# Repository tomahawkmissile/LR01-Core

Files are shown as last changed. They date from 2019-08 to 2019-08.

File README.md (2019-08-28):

# LR01-Core
Core controller of the LR-01 hybrid drone. Controls rotors, critical cooling, battery charge/discharge controllers and realtime sensors.

Aircraft specifications will be posted in another repository.
***Note: these files are about 95% complete.***

Features:
- TI AM3354 Arm Cortex-A8
- 512MB DDR3 (800MHz)
- HDMI out
- 1 Gigabit ethernet
- 2 USB 2.0
- 2 16GB eMCC flash
- 1 Application connector
- 12 layer PCB

***Note: this board may or may not function.***

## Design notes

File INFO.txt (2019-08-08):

**This file contains information about the design files contained here.**

***Further modification needed***

**All units are metric.**

> Board materials + specifications
---> Laminate				FR4
---> Layer count			10
---> Total thickness			1.9mm (Can be rounded to 2.0mm if needed. See note in layer stack section.)
---> Length				97.79mm
---> Width				82.55mm
---> Finish type			HASL
---> Copper weight			35 micrometers for all layers
---> Soldermask color			Matte black
---> Silkscreen location		Both sides (top and bottom)
---> Silkscreen color			White
---> Silkscreen type			LPI
---> Impedance matching			10% tolerance
---> Stacked microvias			No
---> Blind vias				No
---> Buried vias			No
---> Minimum drill diameter		0.15mm
---> Minimum annular ring thickness	0.1mm (adding 0.2mm to the vias diameter)
---> Smallest trace width		0.1016mm
---> Smallest spacing			0.0762mm
---> Via in pad				Yes
---> Via plug				None
---> Stencil				Top and bottom (separate)

> Specific layer stack
---> Copper layer 1			0.035mm
---> Prepreg 1				0.1mm
---> Copper layer 2			0.035mm
---> Core 1				0.22mm
---> Copper layer 3			0.035mm
---> Prepreg 2				0.25mm
---> Copper layer 4			0.035mm
---> Core 2				0.15mm
---> Copper layer 5			0.035mm
---> Prepreg 3				0.2mm
---> Copper layer 6			0.035mm
---> Core 3				0.15mm
---> Copper layer 7			0.035mm
---> Prepreg 4				0.25mm
---> Copper layer 8			0.035mm
---> Core 4				0.22mm
---> Copper layer 9			0.035mm
---> Prepreg 5				0.1mm
---> Copper layer 10			0.035mm

---> Total				1.9mm

>Impedance control stack
---> 50 Ohms between copper layer 1-2, 2-3, 7-8, and 8-9.

***If rounding to 2.0mm is needed, round the Prepreg 3 layer to 0.3mm.***

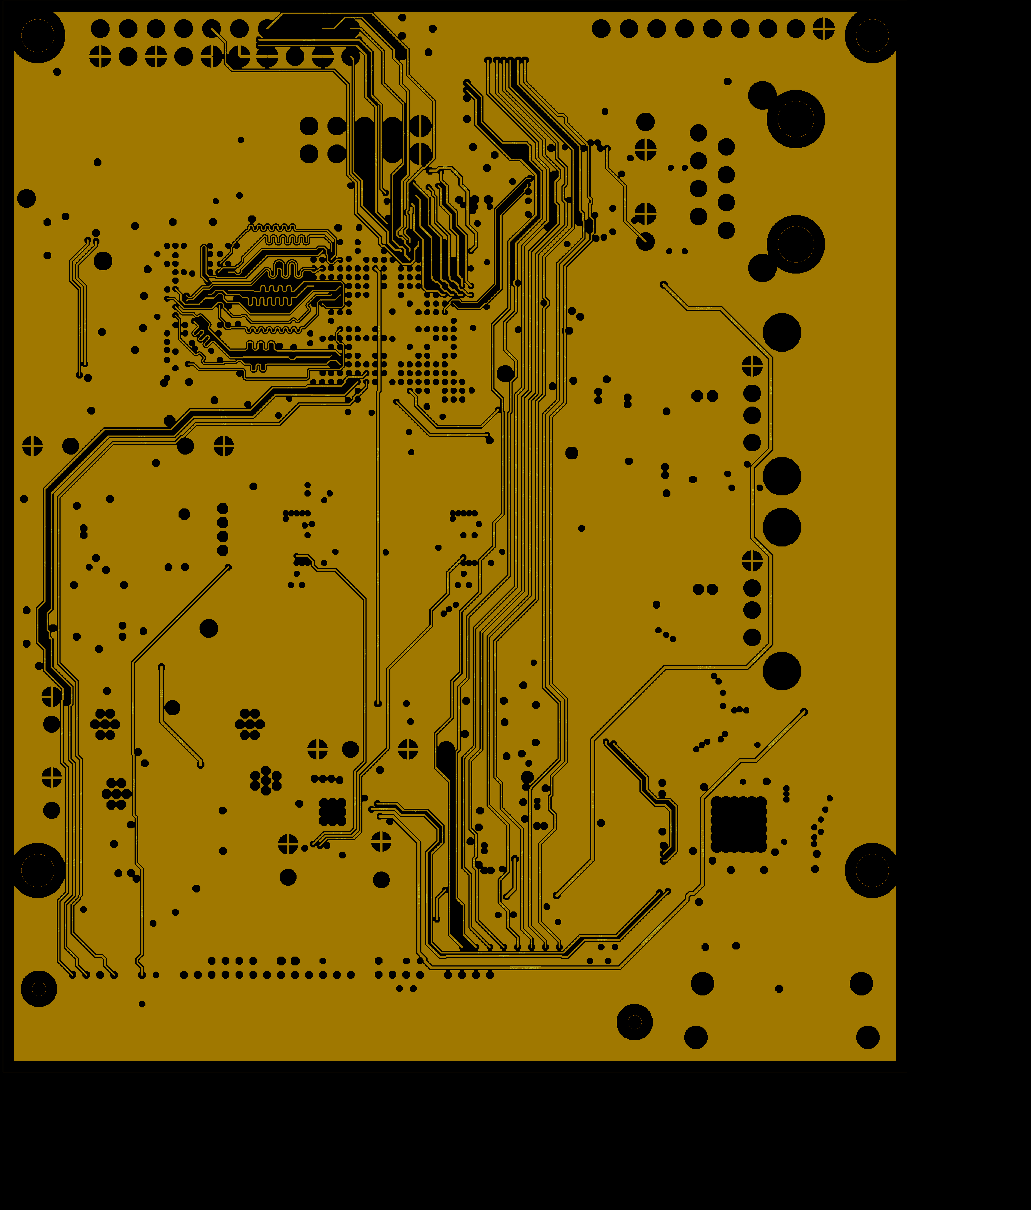
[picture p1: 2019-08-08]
l3.png

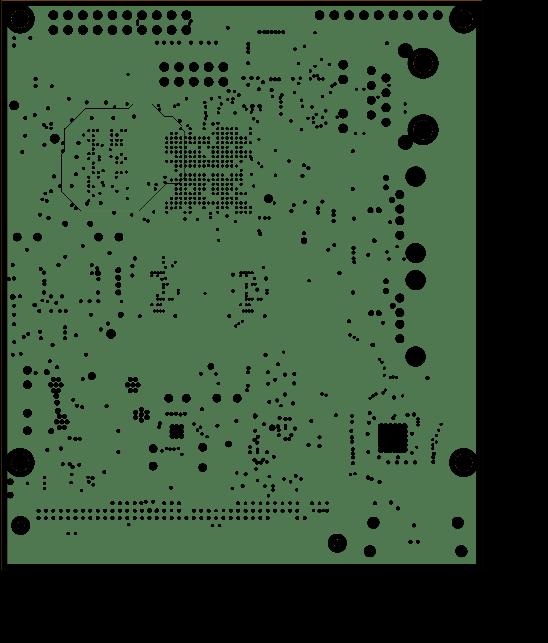
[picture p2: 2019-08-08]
l12.png

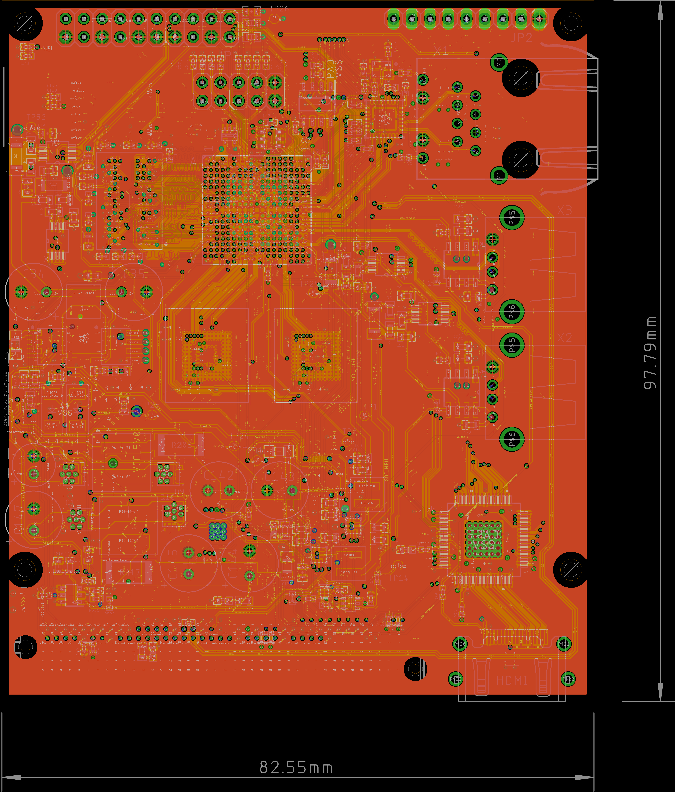
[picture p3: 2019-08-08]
whole-6-22-19.png

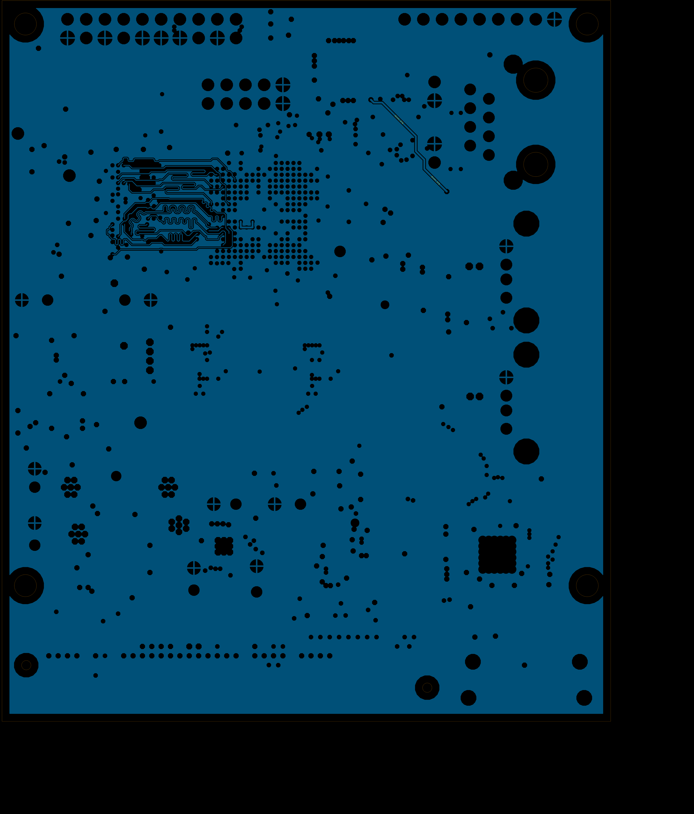
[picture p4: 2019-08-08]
l15.png

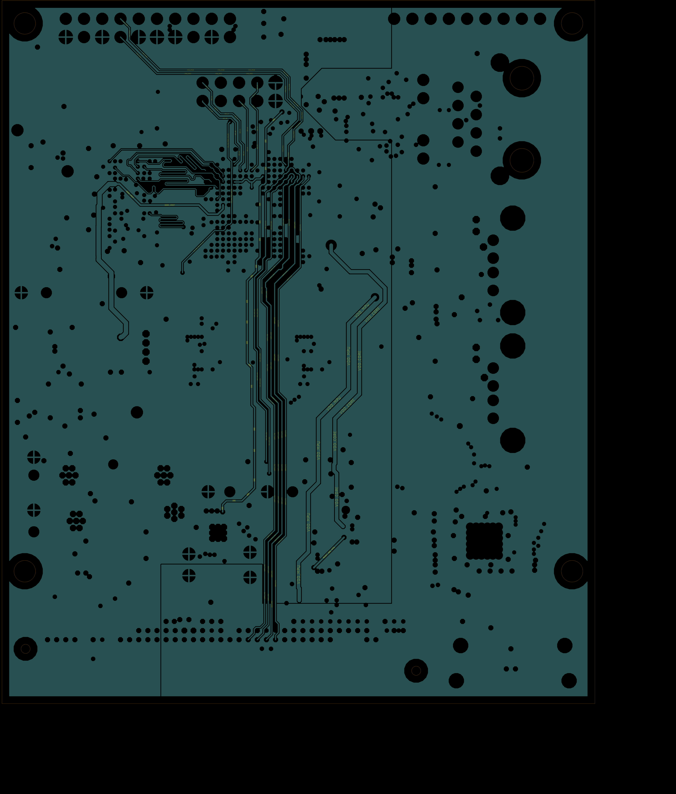
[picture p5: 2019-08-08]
l13.png

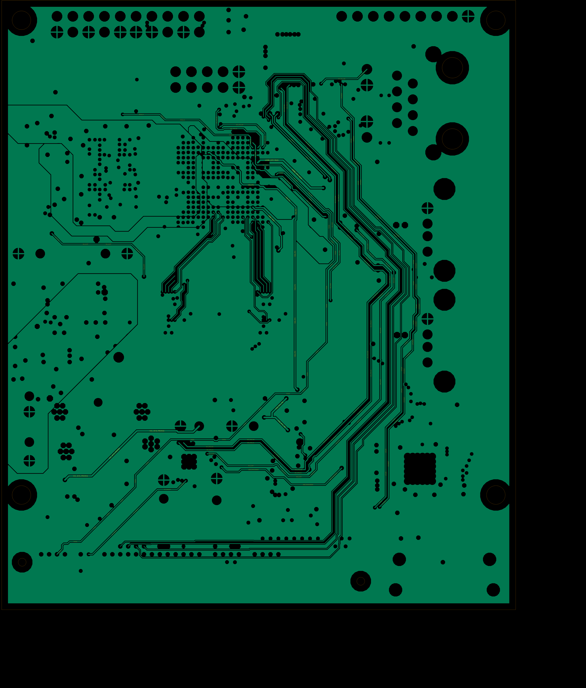
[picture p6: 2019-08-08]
l14.png

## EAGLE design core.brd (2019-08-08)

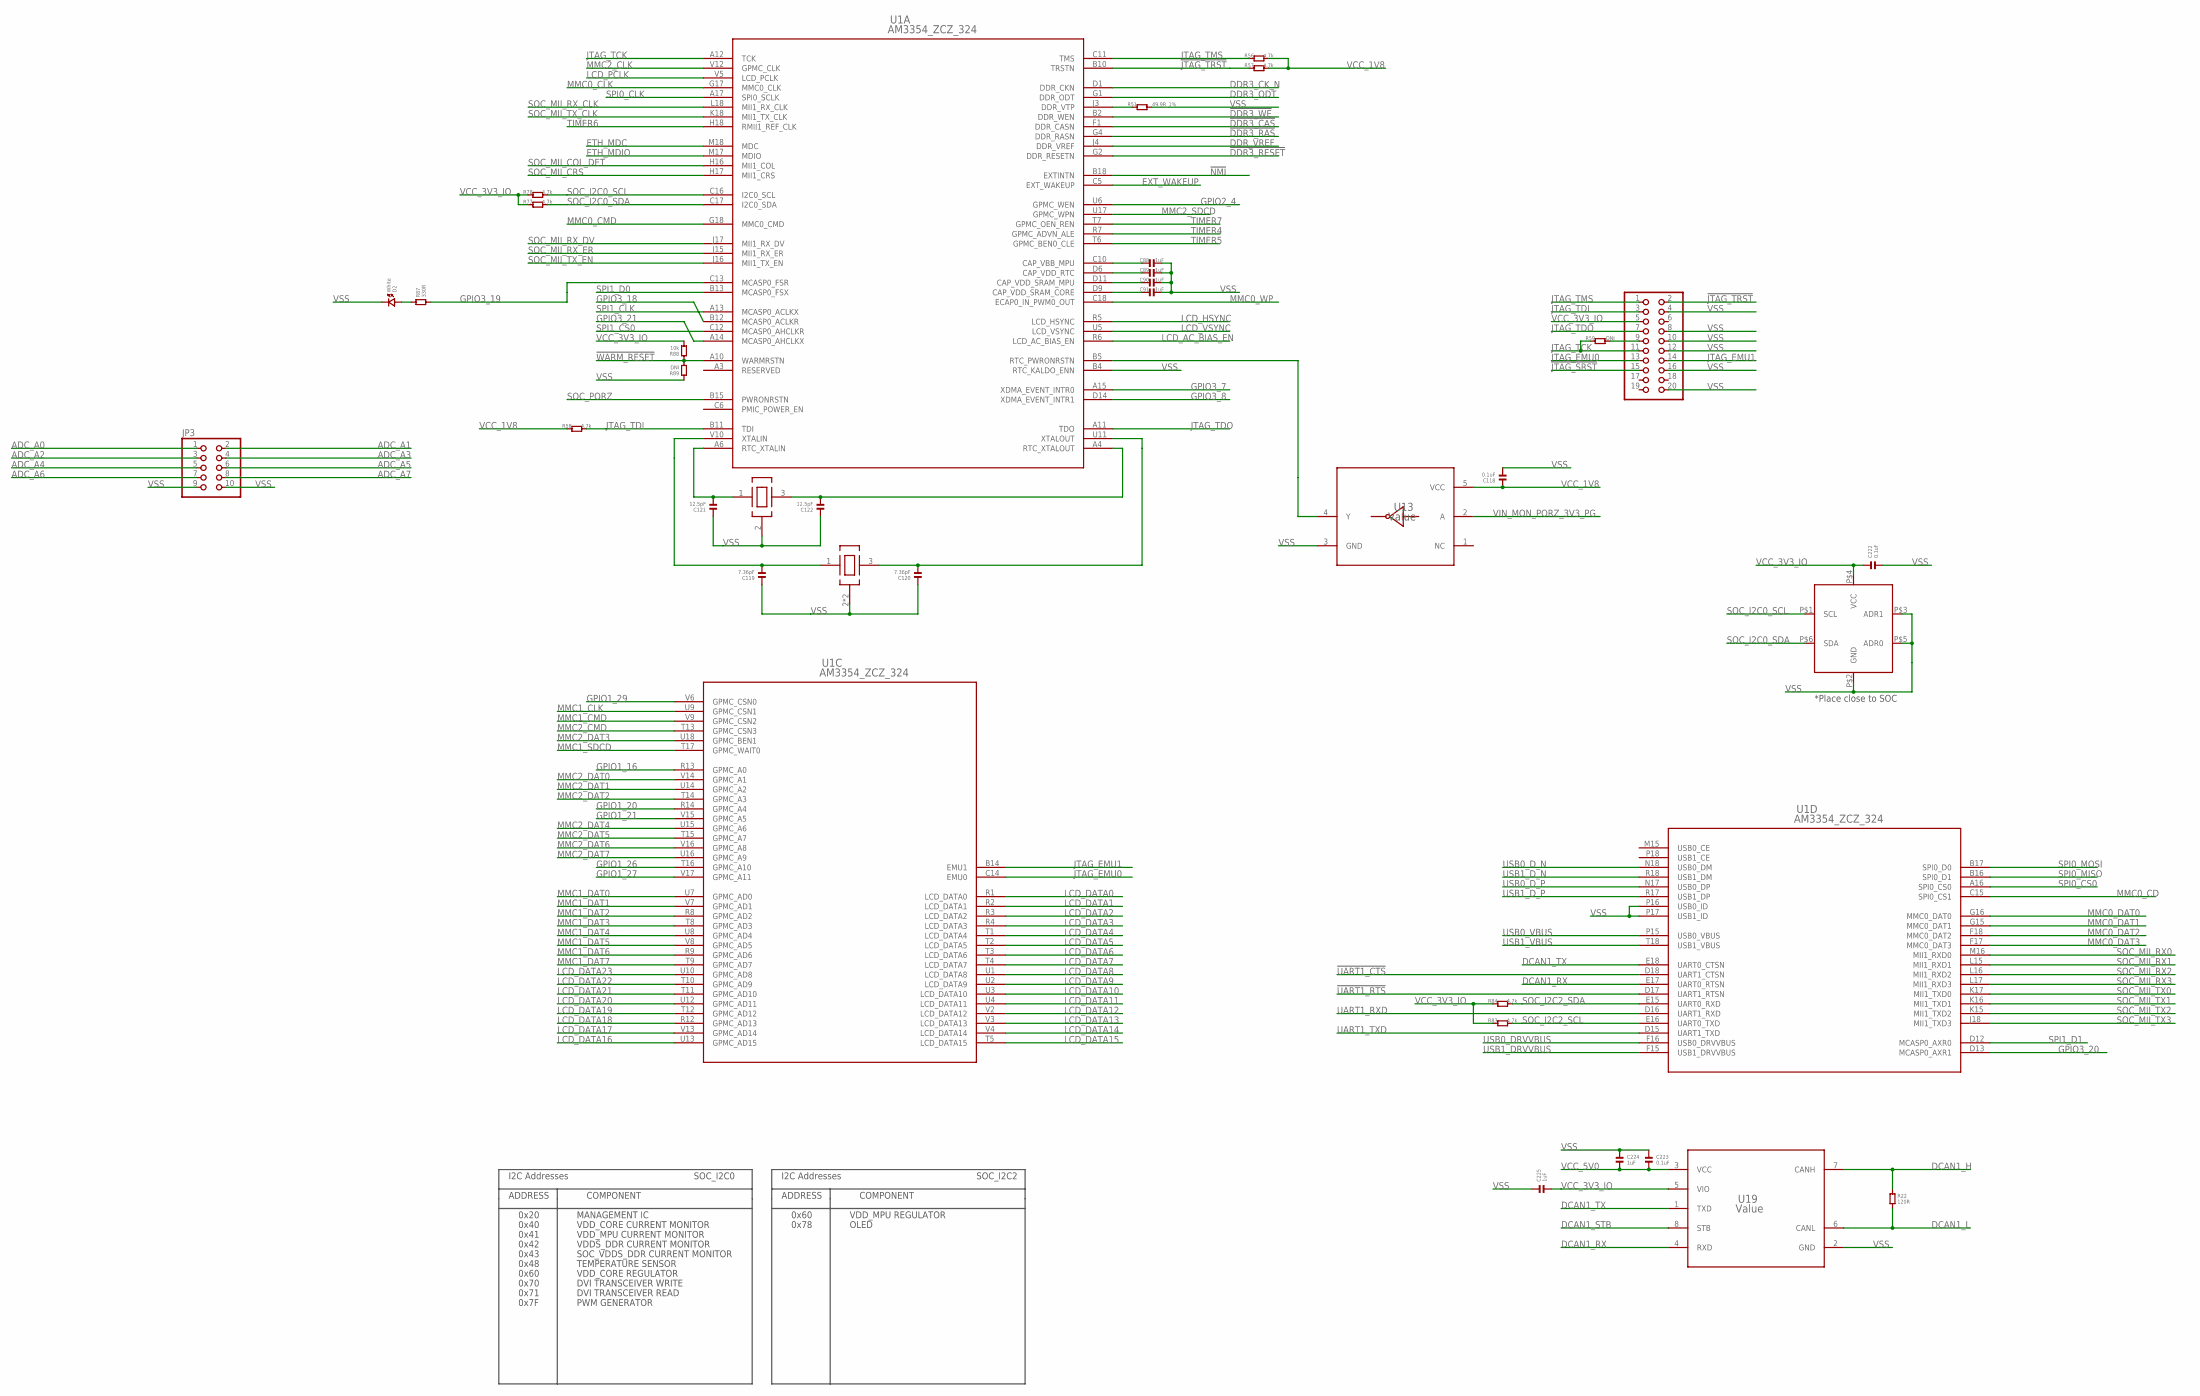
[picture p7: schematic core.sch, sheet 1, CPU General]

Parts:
C88, C89, C90, C91: 1uF; 0201
C118, C222, C223: 0.1uF; 0402
C119, C120: 7.36pF; 0402
C121, C122: 12.5pF; 0402
C224, C225: 1uF; 0402
D2: White; 0603.LED
JP1: PINHD-2X10; 2X10
JP3: PINHD-2X5; 2X05
R22: 120R; 0402
R51: 49.9R_1%; 0201
R56, R57, R58: 4.7k; 0603
R59, R89: DNI; 0402
R77, R78, R83, R84: 4.7k; 0402
R87: 330R; 0603
R88: 10k; 0402
U1: AM3354_ZCZ_324; ZCZ324
U13: Value; DCK0005A_N
U19: Value; D0008A_N
U$5: ECS-.327-12.5-1210B-N-TR; OSCCC120X100X35
U$6: NX3225SA-26.000000MHZ-G3; OSCCC320X250X70
U$9: TMP100; SOT23-6

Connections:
!DDR3_CAS: U1.F1 (DDR_CASN); also elsewhere on the board
!DDR3_RAS: U1.G4 (DDR_RASN); also elsewhere on the board
!DDR3_RESET: U1.G2 (DDR_RESETN); also elsewhere on the board
!DDR3_WE: U1.B2 (DDR_WEN); also elsewhere on the board
!JTAG_SRST: JP1.15
!JTAG_TRST: JP1.2, R57.1, U1.B10 (TRSTN); also elsewhere on the board
!NMI: U1.B18 (EXTINTN); also elsewhere on the board
!UART1_CTS: U1.D18 (UART1_CTSN); also elsewhere on the board
!UART1_RTS: U1.D17 (UART1_RTSN); also elsewhere on the board
!WARM_RESET: R88.1, R89.2, U1.A10 (WARMRSTN); also elsewhere on the board
ADC_A0: JP3.1; also elsewhere on the board
ADC_A1: JP3.2; also elsewhere on the board
ADC_A2: JP3.3; also elsewhere on the board
ADC_A3: JP3.4; also elsewhere on the board
ADC_A4: JP3.5; also elsewhere on the board
ADC_A5: JP3.6; also elsewhere on the board
ADC_A6: JP3.7; also elsewhere on the board
ADC_A7: JP3.8; also elsewhere on the board
DCAN1_H: R22.1, U19.7 (CANH); also elsewhere on the board
DCAN1_L: R22.2, U19.6 (CANL); also elsewhere on the board
DCAN1_RX: U1.E17 (UART0_RTSN), U19.4 (RXD)
DCAN1_STB: U19.8 (STB); also elsewhere on the board
DCAN1_TX: U1.E18 (UART0_CTSN), U19.1 (TXD)
DDR3_CK_N: U1.D1 (DDR_CKN); also elsewhere on the board
DDR3_ODT: U1.G1 (DDR_ODT); also elsewhere on the board
DDR_VREF: U1.J4 (DDR_VREF); also elsewhere on the board
ETH_MDC: U1.M18 (MDC); also elsewhere on the board
ETH_MDIO: U1.M17 (MDIO); also elsewhere on the board
EXT_WAKEUP: U1.C5 (EXT_WAKEUP); also elsewhere on the board
GPIO1_16: U1.R13 (GPMC_A0); also elsewhere on the board
GPIO1_20: U1.R14 (GPMC_A4); also elsewhere on the board
GPIO1_21: U1.V15 (GPMC_A5); also elsewhere on the board
GPIO1_26: U1.T16 (GPMC_A10); also elsewhere on the board
GPIO1_27: U1.V17 (GPMC_A11); also elsewhere on the board
GPIO1_29: U1.V6 (GPMC_CSN0); also elsewhere on the board
GPIO2_4: U1.U6 (GPMC_WEN); also elsewhere on the board
GPIO3_7: U1.A15 (XDMA_EVENT_INTR0); also elsewhere on the board
GPIO3_8: U1.D14 (XDMA_EVENT_INTR1); also elsewhere on the board
GPIO3_18: U1.B12 (MCASP0_ACLKR); also elsewhere on the board
GPIO3_19: R87.2, U1.C13 (MCASP0_FSR); also elsewhere on the board
GPIO3_20: U1.D13 (MCASP0_AXR1); also elsewhere on the board
GPIO3_21: U1.A14 (MCASP0_AHCLKX); also elsewhere on the board
JTAG_EMU0: JP1.13, U1.C14 (EMU0)
JTAG_EMU1: JP1.14, U1.B14 (EMU1)
JTAG_TCK: JP1.11, R59.1, U1.A12 (TCK)
JTAG_TDI: JP1.3, R58.2, U1.B11 (TDI)
JTAG_TDO: JP1.7, U1.A11 (TDO)
JTAG_TMS: JP1.1, R56.1, U1.C11 (TMS)
LCD_AC_BIAS_EN: U1.R6 (LCD_AC_BIAS_EN); also elsewhere on the board
LCD_DATA0: U1.R1 (LCD_DATA0); also elsewhere on the board
LCD_DATA1: U1.R2 (LCD_DATA1); also elsewhere on the board
LCD_DATA2: U1.R3 (LCD_DATA2); also elsewhere on the board
LCD_DATA3: U1.R4 (LCD_DATA3); also elsewhere on the board
LCD_DATA4: U1.T1 (LCD_DATA4); also elsewhere on the board
LCD_DATA5: U1.T2 (LCD_DATA5); also elsewhere on the board
LCD_DATA6: U1.T3 (LCD_DATA6); also elsewhere on the board
LCD_DATA7: U1.T4 (LCD_DATA7); also elsewhere on the board
LCD_DATA8: U1.U1 (LCD_DATA8); also elsewhere on the board
LCD_DATA9: U1.U2 (LCD_DATA9); also elsewhere on the board
LCD_DATA10: U1.U3 (LCD_DATA10); also elsewhere on the board
LCD_DATA11: U1.U4 (LCD_DATA11); also elsewhere on the board
LCD_DATA12: U1.V2 (LCD_DATA12); also elsewhere on the board
LCD_DATA13: U1.V3 (LCD_DATA13); also elsewhere on the board
LCD_DATA14: U1.V4 (LCD_DATA14); also elsewhere on the board
LCD_DATA15: U1.T5 (LCD_DATA15); also elsewhere on the board
LCD_DATA16: U1.U13 (GPMC_AD15); also elsewhere on the board
LCD_DATA17: U1.V13 (GPMC_AD14); also elsewhere on the board
LCD_DATA18: U1.R12 (GPMC_AD13); also elsewhere on the board
LCD_DATA19: U1.T12 (GPMC_AD12); also elsewhere on the board
LCD_DATA20: U1.U12 (GPMC_AD11); also elsewhere on the board
LCD_DATA21: U1.T11 (GPMC_AD10); also elsewhere on the board
LCD_DATA22: U1.T10 (GPMC_AD9); also elsewhere on the board
LCD_DATA23: U1.U10 (GPMC_AD8); also elsewhere on the board
LCD_HSYNC: U1.R5 (LCD_HSYNC); also elsewhere on the board
LCD_PCLK: U1.V5 (LCD_PCLK); also elsewhere on the board
LCD_VSYNC: U1.U5 (LCD_VSYNC); also elsewhere on the board
MMC0_CD: U1.C15 (SPI0_CS1); also elsewhere on the board
MMC0_CLK: U1.G17 (MMC0_CLK); also elsewhere on the board
MMC0_CMD: U1.G18 (MMC0_CMD); also elsewhere on the board
MMC0_DAT0: U1.G16 (MMC0_DAT0); also elsewhere on the board
MMC0_DAT1: U1.G15 (MMC0_DAT1); also elsewhere on the board
MMC0_DAT2: U1.F18 (MMC0_DAT2); also elsewhere on the board
MMC0_DAT3: U1.F17 (MMC0_DAT3); also elsewhere on the board
MMC0_WP: U1.C18 (ECAP0_IN_PWM0_OUT); also elsewhere on the board
MMC1_CLK: U1.U9 (GPMC_CSN1); also elsewhere on the board
MMC1_CMD: U1.V9 (GPMC_CSN2); also elsewhere on the board
MMC1_DAT0: U1.U7 (GPMC_AD0); also elsewhere on the board
MMC1_DAT1: U1.V7 (GPMC_AD1); also elsewhere on the board
MMC1_DAT2: U1.R8 (GPMC_AD2); also elsewhere on the board
MMC1_DAT3: U1.T8 (GPMC_AD3); also elsewhere on the board
MMC1_DAT4: U1.U8 (GPMC_AD4); also elsewhere on the board
MMC1_DAT5: U1.V8 (GPMC_AD5); also elsewhere on the board
MMC1_DAT6: U1.R9 (GPMC_AD6); also elsewhere on the board
MMC1_DAT7: U1.T9 (GPMC_AD7); also elsewhere on the board
MMC1_SDCD: U1.T17 (GPMC_WAIT0)
MMC2_CLK: U1.V12 (GPMC_CLK); also elsewhere on the board
MMC2_CMD: U1.T13 (GPMC_CSN3); also elsewhere on the board
MMC2_DAT0: U1.V14 (GPMC_A1); also elsewhere on the board
MMC2_DAT1: U1.U14 (GPMC_A2); also elsewhere on the board
MMC2_DAT2: U1.T14 (GPMC_A3); also elsewhere on the board
MMC2_DAT3: U1.U18 (GPMC_BEN1); also elsewhere on the board
MMC2_DAT4: U1.U15 (GPMC_A6); also elsewhere on the board
MMC2_DAT5: U1.T15 (GPMC_A7); also elsewhere on the board
MMC2_DAT6: U1.V16 (GPMC_A8); also elsewhere on the board
MMC2_DAT7: U1.U16 (GPMC_A9); also elsewhere on the board
MMC2_SDCD: U1.U17 (GPMC_WPN)
unnamed: JP1.9, R59.2
unnamed: C88.1, U1.C10 (CAP_VBB_MPU)
unnamed: C91.1, U1.D9 (CAP_VDD_SRAM_CORE)
unnamed: C90.1, U1.D11 (CAP_VDD_SRAM_MPU)
unnamed: U1.B5 (RTC_PWRONRSTN), U13.4 (Y)
unnamed: C121.2, U1.A6 (RTC_XTALIN), U$5.1 (XI)
unnamed: C122.2, U1.A4 (RTC_XTALOUT), U$5.3 (XO)
unnamed: C119.2, U1.V10 (XTALIN), U$6.1 (XI)
unnamed: C120.2, U1.U11 (XTALOUT), U$6.3 (XO)
unnamed: R51.1, U1.J3 (DDR_VTP)
unnamed: C89.1, U1.D6 (CAP_VDD_RTC)
unnamed: D2.P$1 (1), R87.1
SOC_I2C0_SCL: R78.2, U1.C16 (I2C0_SCL), U$9.P$1 (SCL); also elsewhere on the board
SOC_I2C0_SDA: R77.2, U1.C17 (I2C0_SDA), U$9.P$6 (SDA); also elsewhere on the board
SOC_I2C2_SCL: R83.2, U1.E16 (UART0_TXD); also elsewhere on the board
SOC_I2C2_SDA: R84.2, U1.E15 (UART0_RXD); also elsewhere on the board
SOC_MII_COL_DET: U1.H16 (MII1_COL); also elsewhere on the board
SOC_MII_CRS: U1.H17 (MII1_CRS); also elsewhere on the board
SOC_MII_RX0: U1.M16 (MII1_RXD0); also elsewhere on the board
SOC_MII_RX1: U1.L15 (MII1_RXD1); also elsewhere on the board
SOC_MII_RX2: U1.L16 (MII1_RXD2); also elsewhere on the board
SOC_MII_RX3: U1.L17 (MII1_RXD3); also elsewhere on the board
SOC_MII_RX_CLK: U1.L18 (MII1_RX_CLK); also elsewhere on the board
SOC_MII_RX_DV: U1.J17 (MII1_RX_DV); also elsewhere on the board
SOC_MII_RX_ER: U1.J15 (MII1_RX_ER); also elsewhere on the board
SOC_MII_TX0: U1.K17 (MII1_TXD0); also elsewhere on the board
SOC_MII_TX1: U1.K16 (MII1_TXD1); also elsewhere on the board
SOC_MII_TX2: U1.K15 (MII1_TXD2); also elsewhere on the board
SOC_MII_TX3: U1.J18 (MII1_TXD3); also elsewhere on the board
SOC_MII_TX_CLK: U1.K18 (MII1_TX_CLK); also elsewhere on the board
SOC_MII_TX_EN: U1.J16 (MII1_TX_EN); also elsewhere on the board
SOC_PORZ: U1.B15 (PWRONRSTN); also elsewhere on the board
SPI0_CLK: U1.A17 (SPI0_SCLK); also elsewhere on the board
SPI0_CS0: U1.A16 (SPI0_CS0); also elsewhere on the board
SPI0_MISO: U1.B16 (SPI0_D1); also elsewhere on the board
SPI0_MOSI: U1.B17 (SPI0_D0); also elsewhere on the board
SPI1_CLK: U1.A13 (MCASP0_ACLKX); also elsewhere on the board
SPI1_CS0: U1.C12 (MCASP0_AHCLKR); also elsewhere on the board
SPI1_D0: U1.B13 (MCASP0_FSX); also elsewhere on the board
SPI1_D1: U1.D12 (MCASP0_AXR0); also elsewhere on the board
TIMER4: U1.R7 (GPMC_ADVN_ALE); also elsewhere on the board
TIMER5: U1.T6 (GPMC_BEN0_CLE); also elsewhere on the board
TIMER6: U1.H18 (RMII1_REF_CLK); also elsewhere on the board
TIMER7: U1.T7 (GPMC_OEN_REN); also elsewhere on the board
UART1_RXD: U1.D16 (UART1_RXD); also elsewhere on the board
UART1_TXD: U1.D15 (UART1_TXD); also elsewhere on the board
USB0_DRVVBUS: U1.F16 (USB0_DRVVBUS); also elsewhere on the board
USB0_D_N: U1.N18 (USB0_DM); also elsewhere on the board
USB0_D_P: U1.N17 (USB0_DP); also elsewhere on the board
USB0_VBUS: U1.P15 (USB0_VBUS); also elsewhere on the board
USB1_DRVVBUS: U1.F15 (USB1_DRVVBUS); also elsewhere on the board
USB1_D_N: U1.R18 (USB1_DM); also elsewhere on the board
USB1_D_P: U1.R17 (USB1_DP); also elsewhere on the board
USB1_VBUS: U1.T18 (USB1_VBUS); also elsewhere on the board
VCC_1V8: C118.1, R56.2, R57.2, R58.1, U13.5 (VCC); also elsewhere on the board
VCC_3V3_IO: C222.1, C225.2, JP1.5, R77.1, R78.1, R83.1, R84.1, R88.2, U19.5 (VIO), U$9.P$4 (VCC); also elsewhere on the board
VCC_5V0: C223.2, C224.2, U19.3 (VCC); also elsewhere on the board
VIN_MON_PORZ_3V3_PG: U13.2 (A); also elsewhere on the board
VPP: U1.M5 (VPP)
VSS: C88.2, C89.2, C90.2, C91.2, C118.2, C119.1, C120.1, C121.1, C122.1, C222.2, C223.1, C224.1, C225.1, D2.P$2 (2), JP1.4, JP1.8, JP1.10, JP1.12, JP1.16, JP1.20, JP3.9, JP3.10, R51.2, R89.1, U1.B4 (RTC_KALDO_ENN), U1.P16 (USB0_ID), U1.P17 (USB1_ID), U13.3 (GND), U19.2 (GND), U$5.2 (VSS), U$6.2 (VSS), U$6.4 (VSS), U$9.P$2 (GND), U$9.P$3 (ADR1), U$9.P$5 (ADR0); also elsewhere on the board

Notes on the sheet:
I2C Addresses
0x20
MANAGEMENT IC
ADDRESS
COMPONENT
0x40
0x41
0x42
0x43
VDD_CORE CURRENT MONITOR
VDD_MPU CURRENT MONITOR
VDDS_DDR CURRENT MONITOR
SOC_VDDS_DDR CURRENT MONITOR
0x60
VDD_CORE REGULATOR
SOC_I2C0
VDD_MPU REGULATOR
SOC_I2C2
0x70
0x71
DVI TRANSCEIVER WRITE
DVI TRANSCEIVER READ
0x78
OLED
0x48
TEMPERATURE SENSOR
*Place close to SOC
0x7F
PWM GENERATOR

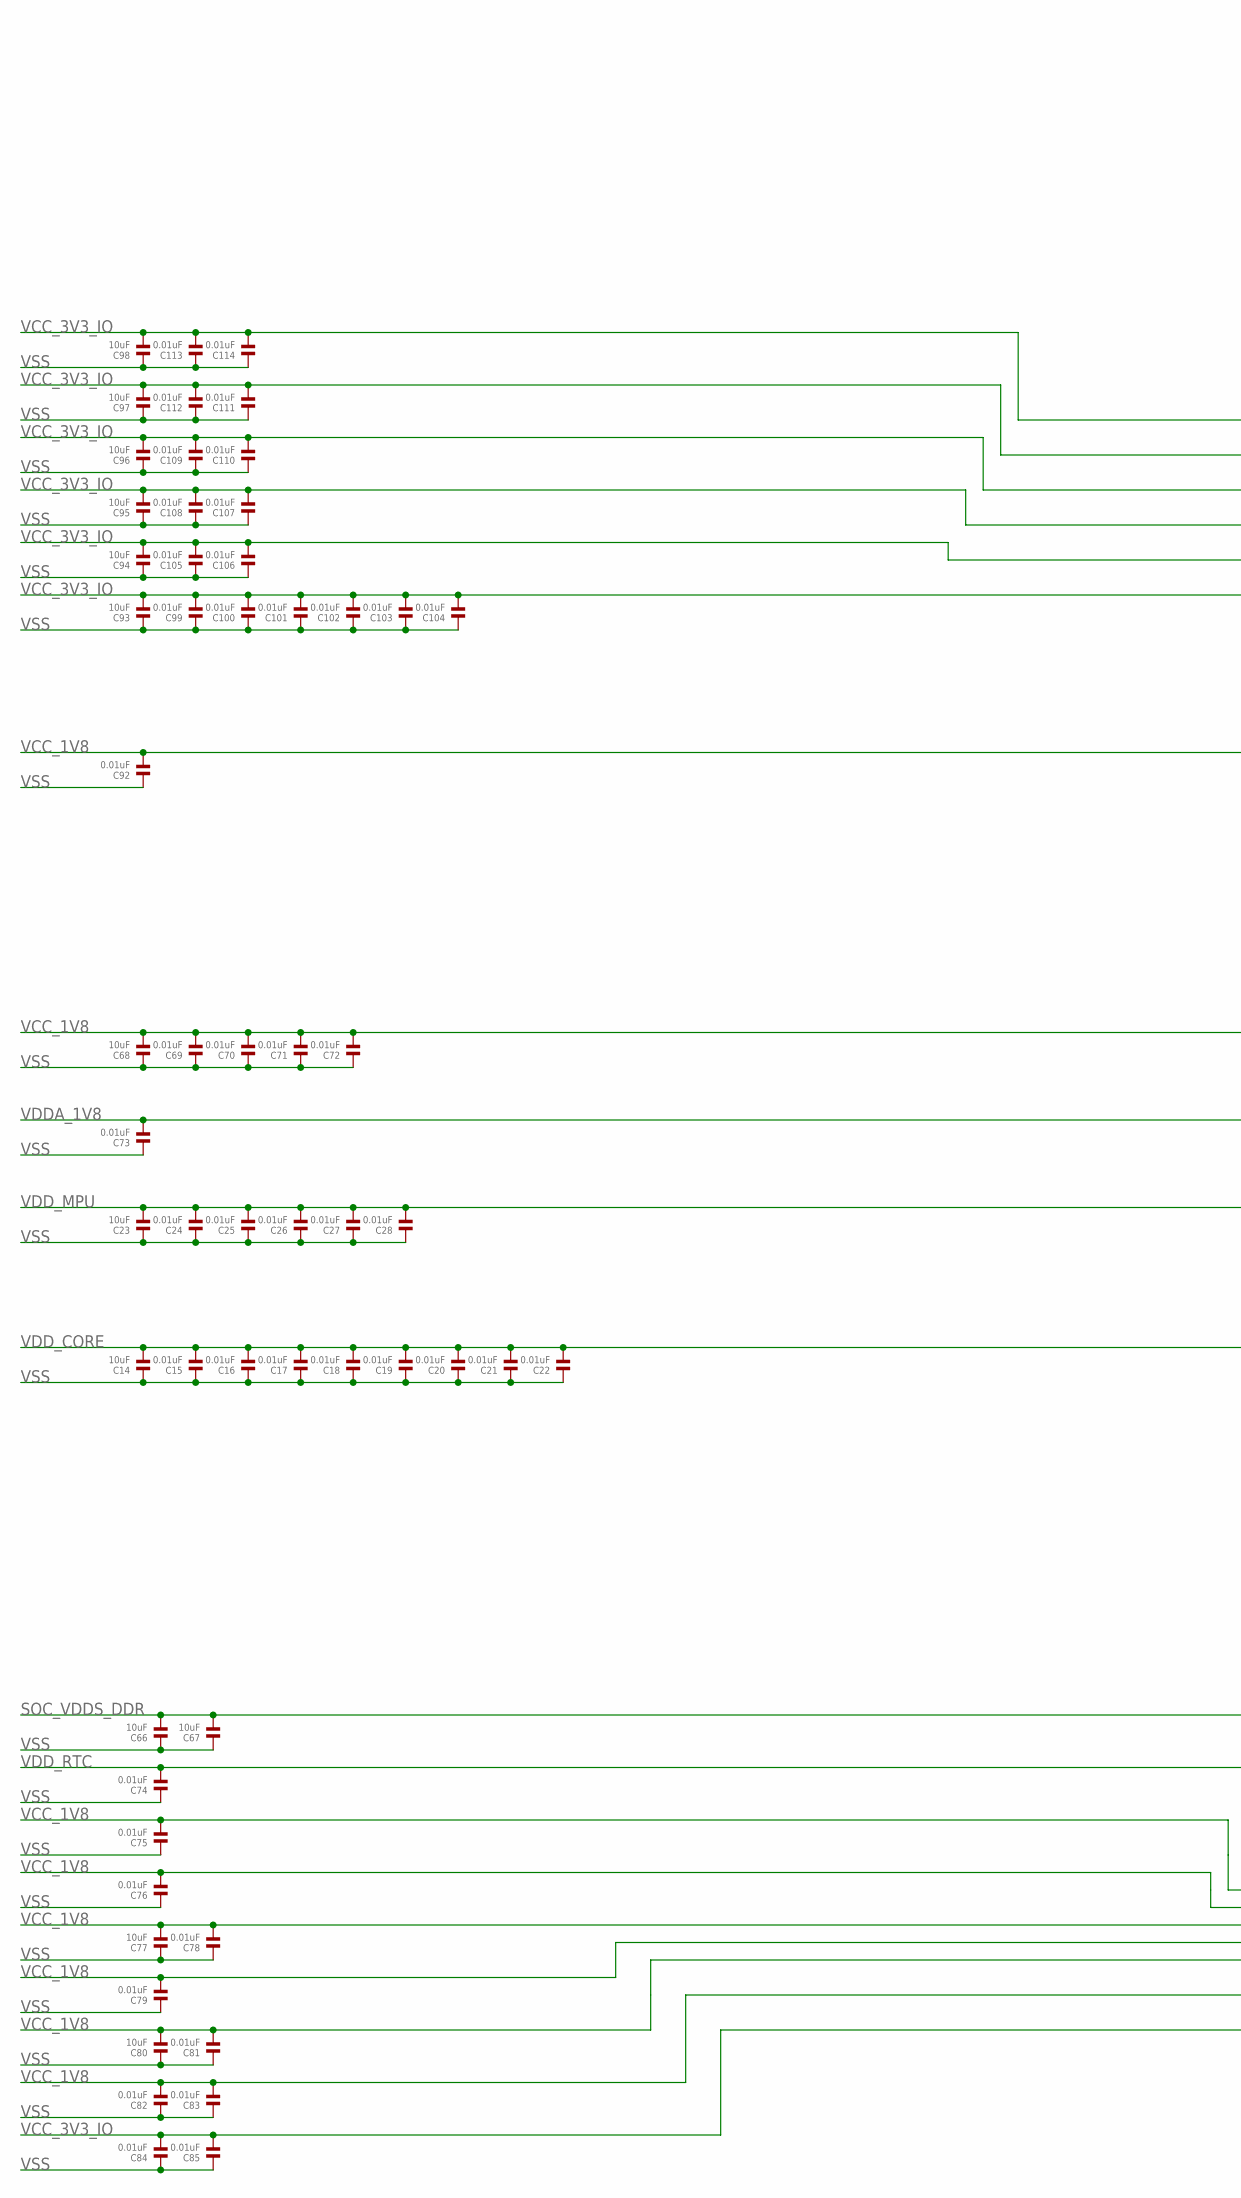
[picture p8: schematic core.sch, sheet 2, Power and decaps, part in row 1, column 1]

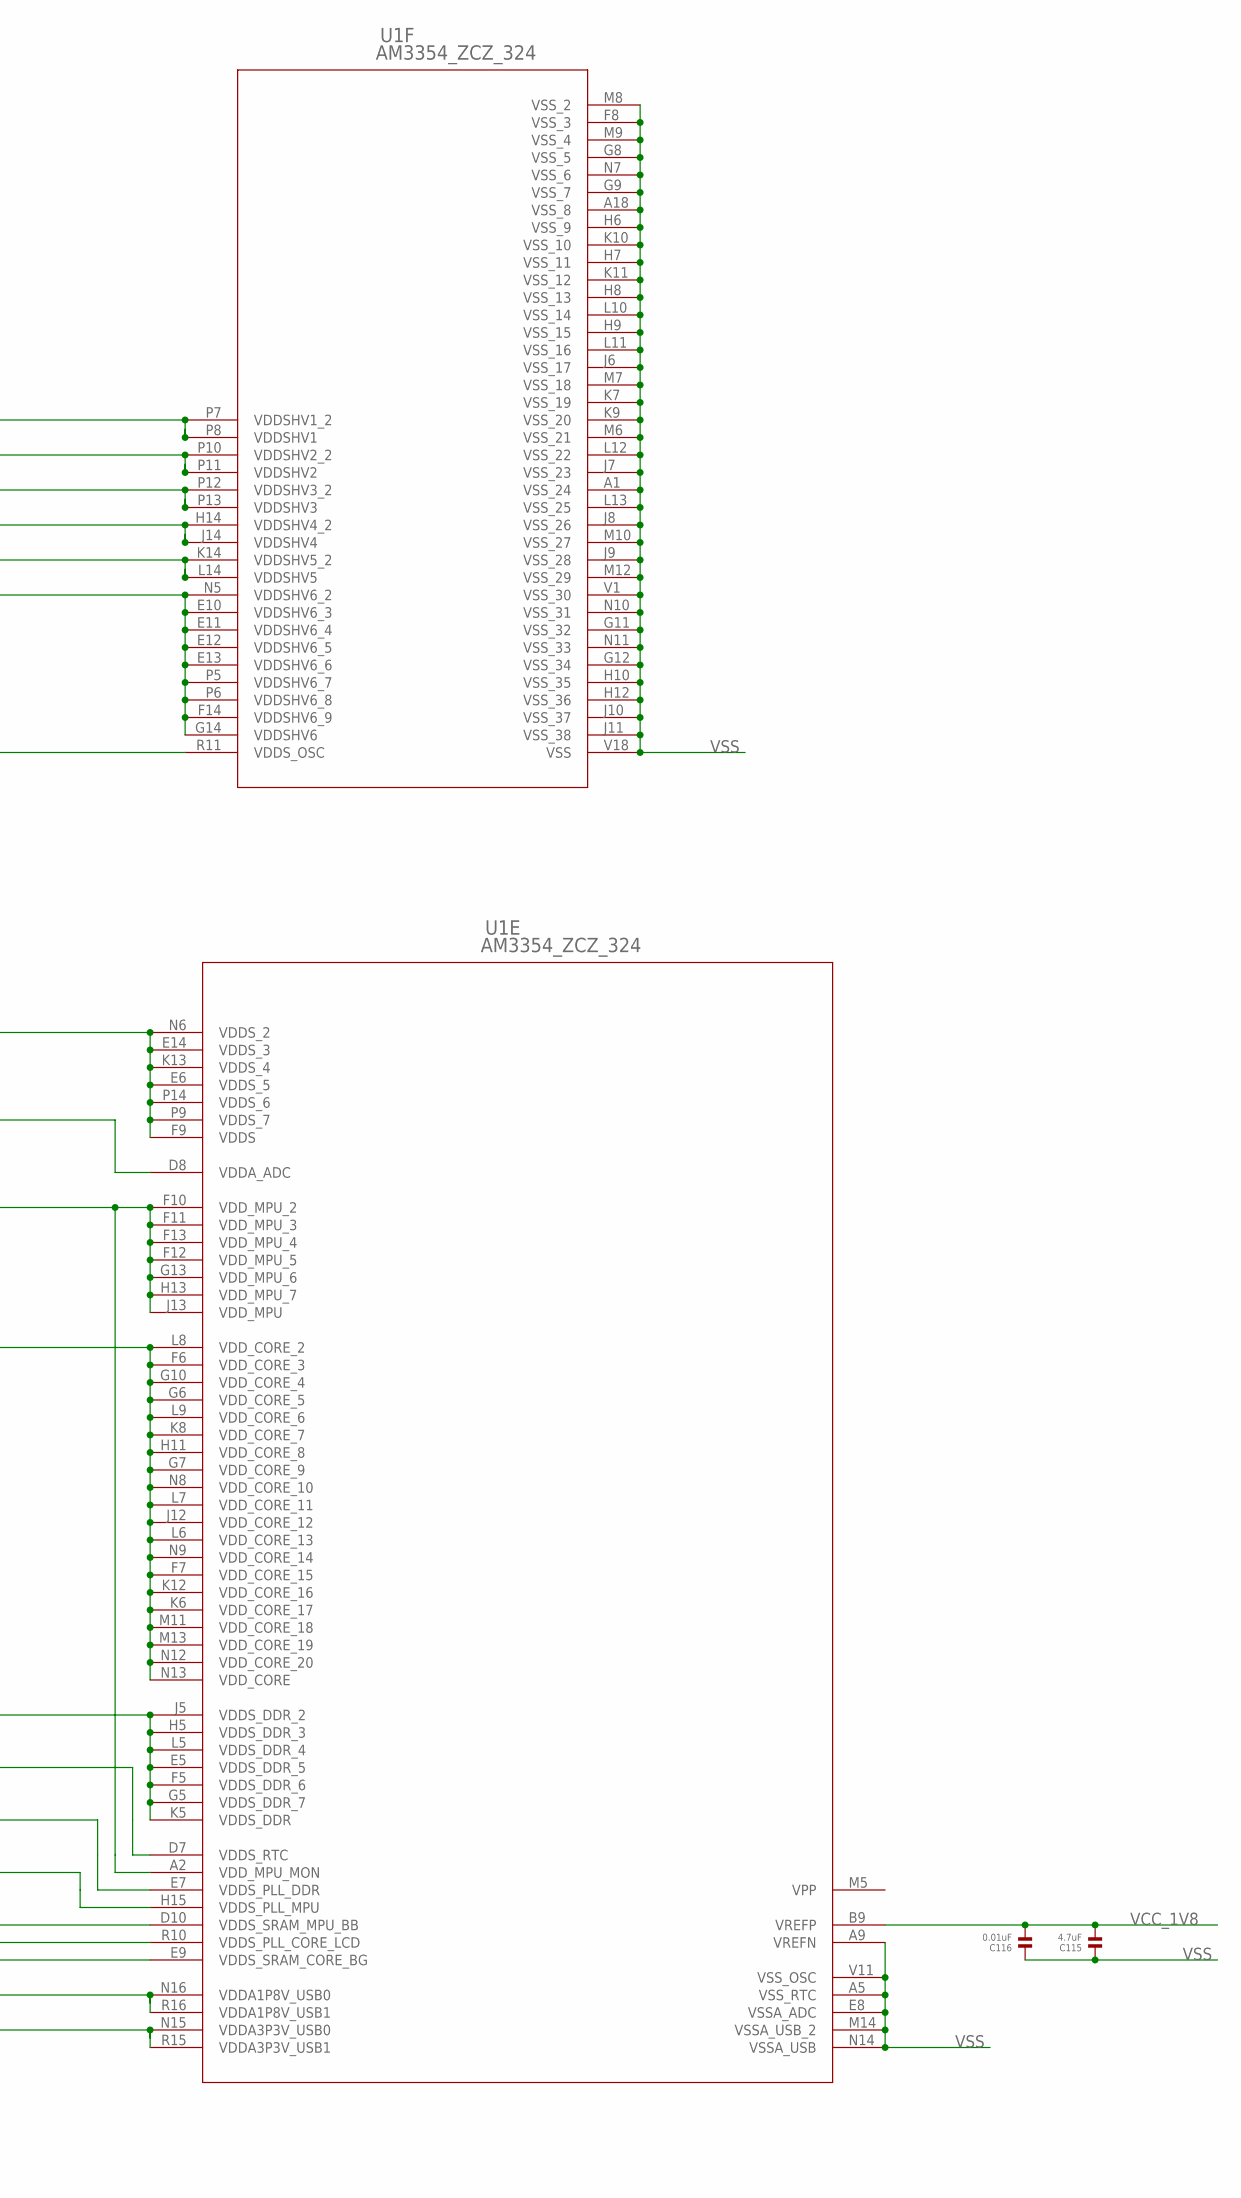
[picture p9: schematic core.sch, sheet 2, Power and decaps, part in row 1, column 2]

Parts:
C14, C23, C66, C67, C68, C77, C80, C93, C94, C95, C96, C97, C98: 10uF; 0402
C15, C16, C17, C18, C19, C20, C21, C22, C24, C25, C26, C27, C28, C69, C70, C71, C72, C73, C74, C75, C76, C78, C79, C81, C82, C83, C84, C85, C92, C99, C100, C101, C102, C103, C104, C105, C106, C107, C108, C109, C110, C111, C112, C113, C114, C116: 0.01uF; 0201
C115: 4.7uF; 0402
U1: AM3354_ZCZ_324; ZCZ324

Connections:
SOC_VDDS_DDR: C66.2, C67.2, U1.E5 (VDDS_DDR_5), U1.F5 (VDDS_DDR_6), U1.G5 (VDDS_DDR_7), U1.H5 (VDDS_DDR_3), U1.J5 (VDDS_DDR_2), U1.K5 (VDDS_DDR), U1.L5 (VDDS_DDR_4); also elsewhere on the board
VCC_1V8: C68.2, C69.2, C70.2, C71.2, C72.2, C75.2, C76.2, C77.2, C78.2, C79.2, C80.2, C81.2, C82.2, C83.2, C92.2, C115.2, C116.2, U1.B9 (VREFP), U1.D10 (VDDS_SRAM_MPU_BB), U1.E6 (VDDS_5), U1.E7 (VDDS_PLL_DDR), U1.E9 (VDDS_SRAM_CORE_BG), U1.E14 (VDDS_3), U1.F9 (VDDS), U1.H15 (VDDS_PLL_MPU), U1.K13 (VDDS_4), U1.N6 (VDDS_2), U1.N16 (VDDA1P8V_USB0), U1.P9 (VDDS_7), U1.P14 (VDDS_6), U1.R10 (VDDS_PLL_CORE_LCD), U1.R11 (VDDS_OSC), U1.R16 (VDDA1P8V_USB1); also elsewhere on the board
VCC_3V3_IO: C84.2, C85.2, C93.2, C94.2, C95.2, C96.2, C97.2, C98.2, C99.2, C100.2, C101.2, C102.2, C103.2, C104.2, C105.2, C106.2, C107.2, C108.2, C109.2, C110.2, C111.2, C112.2, C113.2, C114.2, U1.E10 (VDDSHV6_3), U1.E11 (VDDSHV6_4), U1.E12 (VDDSHV6_5), U1.E13 (VDDSHV6_6), U1.F14 (VDDSHV6_9), U1.G14 (VDDSHV6), U1.H14 (VDDSHV4_2), U1.J14 (VDDSHV4), U1.K14 (VDDSHV5_2), U1.L14 (VDDSHV5), U1.N5 (VDDSHV6_2), U1.N15 (VDDA3P3V_USB0), U1.P5 (VDDSHV6_7), U1.P6 (VDDSHV6_8), U1.P7 (VDDSHV1_2), U1.P8 (VDDSHV1), U1.P10 (VDDSHV2_2), U1.P11 (VDDSHV2), U1.P12 (VDDSHV3_2), U1.P13 (VDDSHV3), U1.R15 (VDDA3P3V_USB1); also elsewhere on the board
VDDA_1V8: C73.2, U1.D8 (VDDA_ADC); also elsewhere on the board
VDD_CORE: C14.2, C15.2, C16.2, C17.2, C18.2, C19.2, C20.2, C21.2, C22.2, U1.F6 (VDD_CORE_3), U1.F7 (VDD_CORE_15), U1.G6 (VDD_CORE_5), U1.G7 (VDD_CORE_9), U1.G10 (VDD_CORE_4), U1.H11 (VDD_CORE_8), U1.J12 (VDD_CORE_12), U1.K6 (VDD_CORE_17), U1.K8 (VDD_CORE_7), U1.K12 (VDD_CORE_16), U1.L6 (VDD_CORE_13), U1.L7 (VDD_CORE_11), U1.L8 (VDD_CORE_2), U1.L9 (VDD_CORE_6), U1.M11 (VDD_CORE_18), U1.M13 (VDD_CORE_19), U1.N8 (VDD_CORE_10), U1.N9 (VDD_CORE_14), U1.N12 (VDD_CORE_20), U1.N13 (VDD_CORE); also elsewhere on the board
VDD_MPU: C23.2, C24.2, C25.2, C26.2, C27.2, C28.2, U1.A2 (VDD_MPU_MON), U1.F10 (VDD_MPU_2), U1.F11 (VDD_MPU_3), U1.F12 (VDD_MPU_5), U1.F13 (VDD_MPU_4), U1.G13 (VDD_MPU_6), U1.H13 (VDD_MPU_7), U1.J13 (VDD_MPU); also elsewhere on the board
VDD_RTC: C74.2, U1.D7 (VDDS_RTC); also elsewhere on the board
VPP: U1.M5 (VPP)
VSS: C14.1, C15.1, C16.1, C17.1, C18.1, C19.1, C20.1, C21.1, C22.1, C23.1, C24.1, C25.1, C26.1, C27.1, C28.1, C66.1, C67.1, C68.1, C69.1, C70.1, C71.1, C72.1, C73.1, C74.1, C75.1, C76.1, C77.1, C78.1, C79.1, C80.1, C81.1, C82.1, C83.1, C84.1, C85.1, C92.1, C93.1, C94.1, C95.1, C96.1, C97.1, C98.1, C99.1, C100.1, C101.1, C102.1, C103.1, C104.1, C105.1, C106.1, C107.1, C108.1, C109.1, C110.1, C111.1, C112.1, C113.1, C114.1, C115.1, C116.1, U1.A1 (VSS_24), U1.A5 (VSS_RTC), U1.A9 (VREFN), U1.A18 (VSS_8), U1.E8 (VSSA_ADC), U1.F8 (VSS_3), U1.G8 (VSS_5), U1.G9 (VSS_7), U1.G11 (VSS_32), U1.G12 (VSS_34), U1.H6 (VSS_9), U1.H7 (VSS_11), U1.H8 (VSS_13), U1.H9 (VSS_15), U1.H10 (VSS_35), U1.H12 (VSS_36), U1.J6 (VSS_17), U1.J7 (VSS_23), U1.J8 (VSS_26), U1.J9 (VSS_28), U1.J10 (VSS_37), U1.J11 (VSS_38), U1.K7 (VSS_19), U1.K9 (VSS_20), U1.K10 (VSS_10), U1.K11 (VSS_12), U1.L10 (VSS_14), U1.L11 (VSS_16), U1.L12 (VSS_22), U1.L13 (VSS_25), U1.M6 (VSS_21), U1.M7 (VSS_18), U1.M8 (VSS_2), U1.M9 (VSS_4), U1.M10 (VSS_27), U1.M12 (VSS_29), U1.M14 (VSSA_USB_2), U1.N7 (VSS_6), U1.N10 (VSS_31), U1.N11 (VSS_33), U1.N14 (VSSA_USB), U1.V1 (VSS_30), U1.V11 (VSS_OSC), U1.V18 (VSS); also elsewhere on the board

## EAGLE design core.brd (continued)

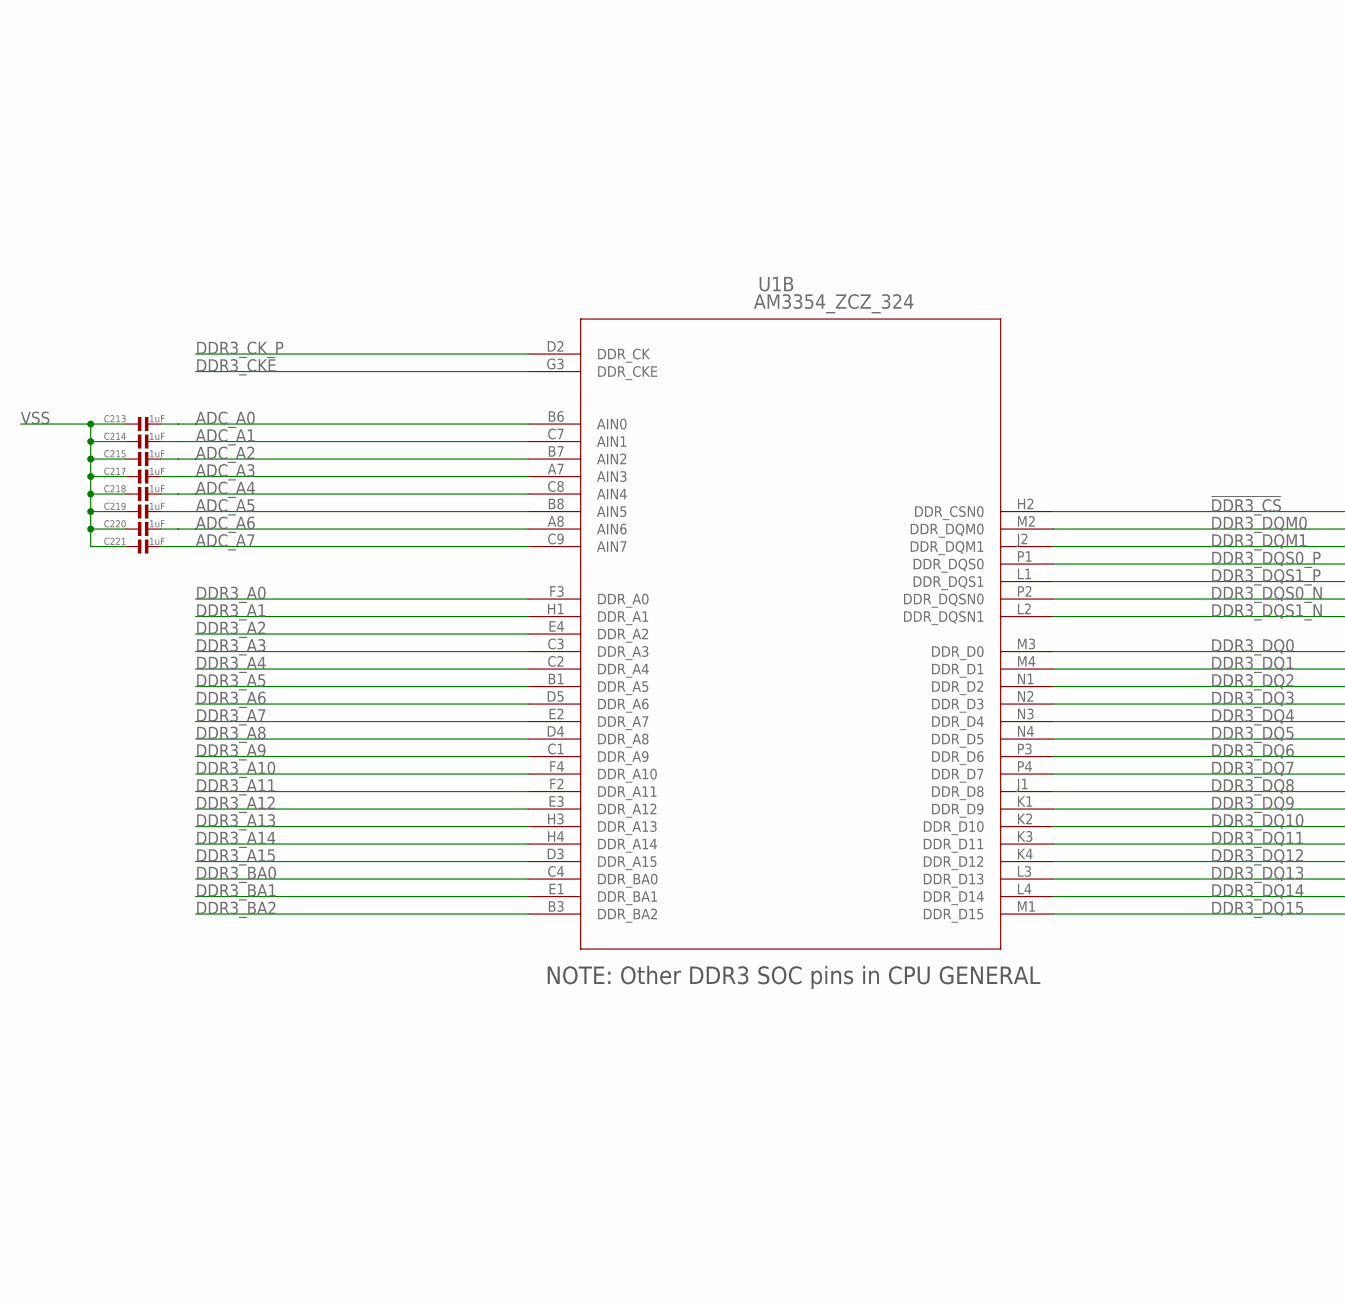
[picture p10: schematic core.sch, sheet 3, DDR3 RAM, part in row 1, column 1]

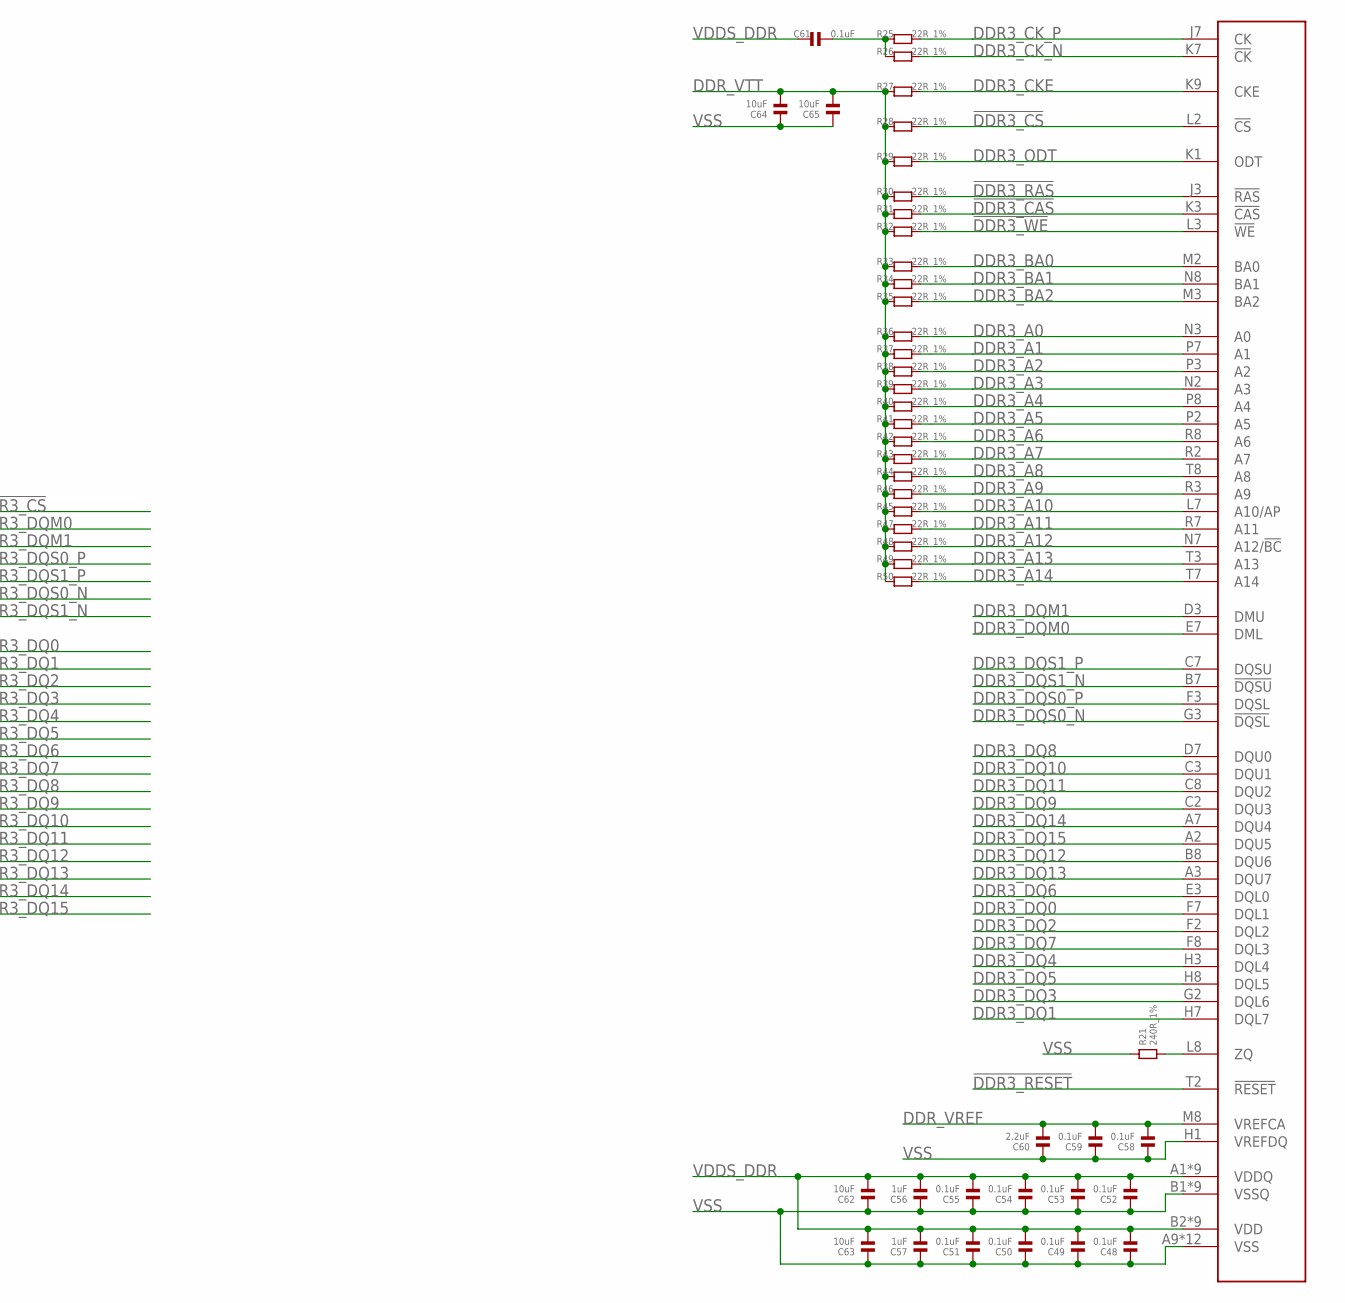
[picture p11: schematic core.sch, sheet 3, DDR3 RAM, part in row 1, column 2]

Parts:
C48, C49, C50, C51, C52, C53, C54, C55, C59: 0.1uF; 0402
C56, C57, C213, C214, C215, C217, C218, C219, C220, C221: 1uF; 0402
C58, C61: 0.1uF; 0201
C60: 2.2uF; 0603
C62, C63: 10uF; 0603
C64, C65: 10uF; 0402
R21: 240R_1%; 0402
R25, R26, R27, R28, R29, R30, R31, R32, R33, R34, R35, R36, R37, R38, R39, R40, R41, R42, R43, R44, R45, R46, R47, R48, R49, R50: 22R_1%; 0201
U1: AM3354_ZCZ_324; ZCZ324
U9: AS4C256M16D3B-12BIN; BGA144C80P9X16_1350X900X120

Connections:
!DDR3_CAS: R31.2, U9.K3 (!CAS); also elsewhere on the board
!DDR3_CS: R28.2, U1.H2 (DDR_CSN0), U9.L2 (!CS)
!DDR3_RAS: R30.2, U9.J3 (!RAS); also elsewhere on the board
!DDR3_RESET: U9.T2 (!RESET); also elsewhere on the board
!DDR3_WE: R32.2, U9.L3 (!WE); also elsewhere on the board
ADC_A0: C213.2, U1.B6 (AIN0); also elsewhere on the board
ADC_A1: C214.2, U1.C7 (AIN1); also elsewhere on the board
ADC_A2: C215.2, U1.B7 (AIN2); also elsewhere on the board
ADC_A3: C217.2, U1.A7 (AIN3); also elsewhere on the board
ADC_A4: C218.2, U1.C8 (AIN4); also elsewhere on the board
ADC_A5: C219.2, U1.B8 (AIN5); also elsewhere on the board
ADC_A6: C220.2, U1.A8 (AIN6); also elsewhere on the board
ADC_A7: C221.2, U1.C9 (AIN7); also elsewhere on the board
DDR3_A0: R36.2, U1.F3 (DDR_A0), U9.N3 (A0)
DDR3_A1: R37.2, U1.H1 (DDR_A1), U9.P7 (A1)
DDR3_A2: R38.2, U1.E4 (DDR_A2), U9.P3 (A2)
DDR3_A3: R39.2, U1.C3 (DDR_A3), U9.N2 (A3)
DDR3_A4: R40.2, U1.C2 (DDR_A4), U9.P8 (A4)
DDR3_A5: R41.2, U1.B1 (DDR_A5), U9.P2 (A5)
DDR3_A6: R42.2, U1.D5 (DDR_A6), U9.R8 (A6)
DDR3_A7: R43.2, U1.E2 (DDR_A7), U9.R2 (A7)
DDR3_A8: R44.2, U1.D4 (DDR_A8), U9.T8 (A8)
DDR3_A9: R46.2, U1.C1 (DDR_A9), U9.R3 (A9)
DDR3_A10: R45.2, U1.F4 (DDR_A10), U9.L7 (A10/AP)
DDR3_A11: R47.2, U1.F2 (DDR_A11), U9.R7 (A11)
DDR3_A12: R48.2, U1.E3 (DDR_A12), U9.N7 (A12/!BC)
DDR3_A13: R49.2, U1.H3 (DDR_A13), U9.T3 (A13)
DDR3_A14: R50.2, U1.H4 (DDR_A14), U9.T7 (A14)
DDR3_A15: U1.D3 (DDR_A15)
DDR3_BA0: R33.2, U1.C4 (DDR_BA0), U9.M2 (BA0)
DDR3_BA1: R34.2, U1.E1 (DDR_BA1), U9.N8 (BA1)
DDR3_BA2: R35.2, U1.B3 (DDR_BA2), U9.M3 (BA2)
DDR3_CKE: R27.2, U1.G3 (DDR_CKE), U9.K9 (CKE)
DDR3_CK_N: R26.2, U9.K7 (!CK); also elsewhere on the board
DDR3_CK_P: R25.2, U1.D2 (DDR_CK), U9.J7 (CK)
DDR3_DQ0: U1.M3 (DDR_D0), U9.F7 (DQL1)
DDR3_DQ1: U1.M4 (DDR_D1), U9.H7 (DQL7)
DDR3_DQ2: U1.N1 (DDR_D2), U9.F2 (DQL2)
DDR3_DQ3: U1.N2 (DDR_D3), U9.G2 (DQL6)
DDR3_DQ4: U1.N3 (DDR_D4), U9.H3 (DQL4)
DDR3_DQ5: U1.N4 (DDR_D5), U9.H8 (DQL5)
DDR3_DQ6: U1.P3 (DDR_D6), U9.E3 (DQL0)
DDR3_DQ7: U1.P4 (DDR_D7), U9.F8 (DQL3)
DDR3_DQ8: U1.J1 (DDR_D8), U9.D7 (DQU0)
DDR3_DQ9: U1.K1 (DDR_D9), U9.C2 (DQU3)
DDR3_DQ10: U1.K2 (DDR_D10), U9.C3 (DQU1)
DDR3_DQ11: U1.K3 (DDR_D11), U9.C8 (DQU2)
DDR3_DQ12: U1.K4 (DDR_D12), U9.B8 (DQU6)
DDR3_DQ13: U1.L3 (DDR_D13), U9.A3 (DQU7)
DDR3_DQ14: U1.L4 (DDR_D14), U9.A7 (DQU4)
DDR3_DQ15: U1.M1 (DDR_D15), U9.A2 (DQU5)
DDR3_DQM0: U1.M2 (DDR_DQM0), U9.E7 (DML)
DDR3_DQM1: U1.J2 (DDR_DQM1), U9.D3 (DMU)
DDR3_DQS0_N: U1.P2 (DDR_DQSN0), U9.G3 (!DQSL)
DDR3_DQS0_P: U1.P1 (DDR_DQS0), U9.F3 (DQSL)
DDR3_DQS1_N: U1.L2 (DDR_DQSN1), U9.B7 (!DQSU)
DDR3_DQS1_P: U1.L1 (DDR_DQS1), U9.C7 (DQSU)
DDR3_ODT: R29.2, U9.K1 (ODT); also elsewhere on the board
DDR_VREF: C58.2, C59.2, C60.2, U9.M8 (VREFCA); also elsewhere on the board
DDR_VTT: C64.2, C65.2, R27.1, R28.1, R29.1, R30.1, R31.1, R32.1, R33.1, R34.1, R35.1, R36.1, R37.1, R38.1, R39.1, R40.1, R41.1, R42.1, R43.1, R44.1, R45.1, R46.1, R47.1, R48.1, R49.1, R50.1; also elsewhere on the board
unnamed: R21.2, U9.L8 (ZQ)
unnamed: C61.2, R25.1, R26.1
VDDS_DDR: C48.2, C49.2, C50.2, C51.2, C52.2, C53.2, C54.2, C55.2, C56.2, C57.2, C61.1, C62.2, C63.2, U9.A1 (VDDQ), U9.A8 (VDDQ), U9.B2 (VDD), U9.C1 (VDDQ), U9.C9 (VDDQ), U9.D2 (VDDQ), U9.D9 (VDD), U9.E9 (VDDQ), U9.F1 (VDDQ), U9.G7 (VDD), U9.H2 (VDDQ), U9.H9 (VDDQ), U9.K2 (VDD), U9.K8 (VDD), U9.N1 (VDD), U9.N9 (VDD), U9.R1 (VDD), U9.R9 (VDD); also elsewhere on the board
VPP: U1.M5 (VPP)
VSS: C48.1, C49.1, C50.1, C51.1, C52.1, C53.1, C54.1, C55.1, C56.1, C57.1, C58.1, C59.1, C60.1, C62.1, C63.1, C64.1, C65.1, C213.1, C214.1, C215.1, C217.1, C218.1, C219.1, C220.1, C221.1, R21.1, U9.A9 (VSS), U9.B1 (VSSQ), U9.B3 (VSS), U9.B9 (VSSQ), U9.D1 (VSSQ), U9.D8 (VSSQ), U9.E1 (VSS), U9.E2 (VSSQ), U9.E8 (VSSQ), U9.F9 (VSSQ), U9.G1 (VSSQ), U9.G8 (VSS), U9.G9 (VSSQ), U9.H1 (VREFDQ), U9.J2 (VSS), U9.J8 (VSS), U9.M1 (VSS), U9.M9 (VSS), U9.P1 (VSS), U9.P9 (VSS), U9.T1 (VSS), U9.T9 (VSS); also elsewhere on the board

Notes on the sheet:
NOTE: Other DDR3 SOC pins in CPU GENERAL

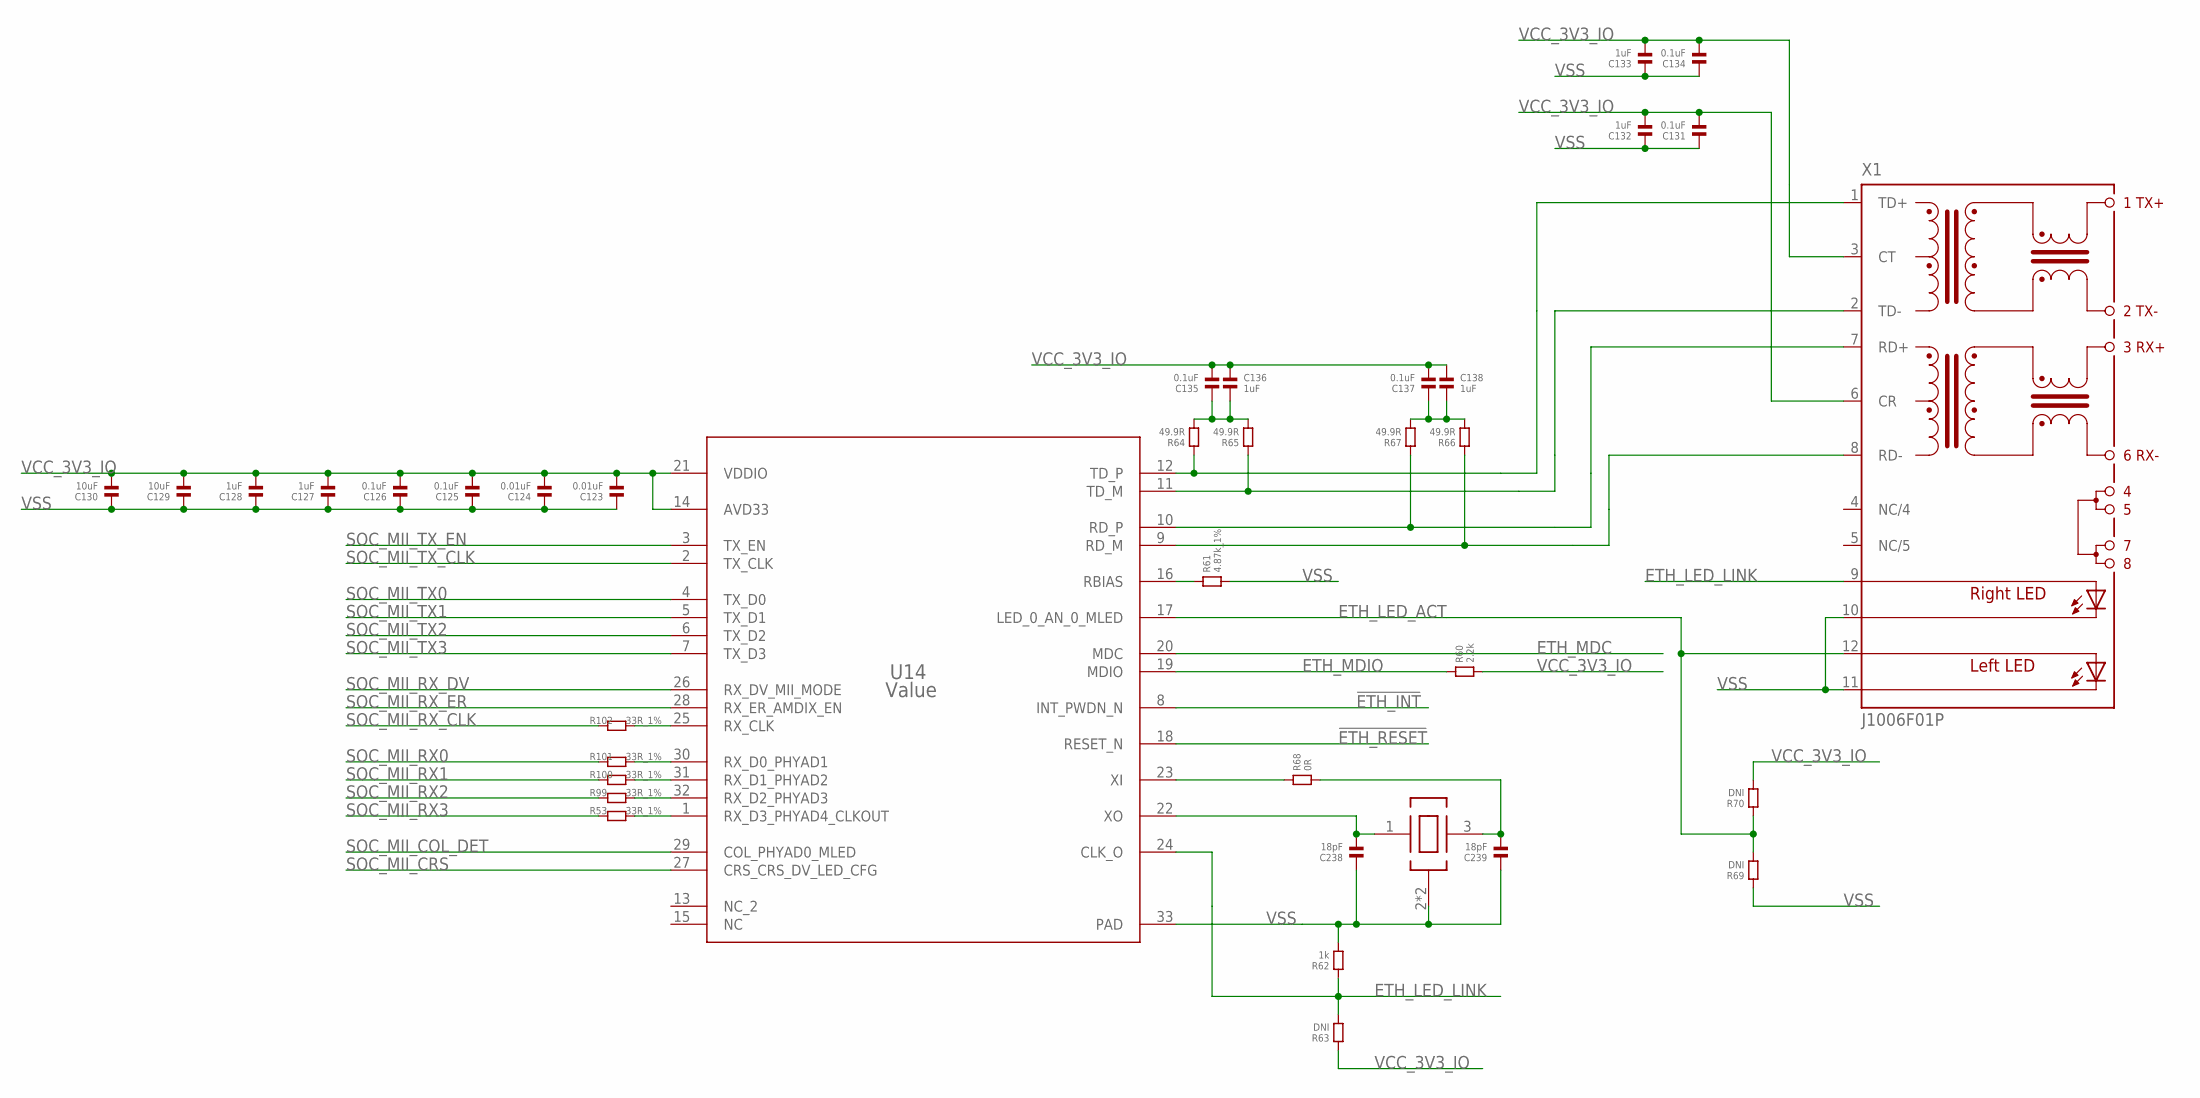
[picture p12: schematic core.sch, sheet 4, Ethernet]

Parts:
C123, C124: 0.01uF; 0402
C125, C126, C131, C134, C135, C137: 0.1uF; 0402
C127, C128, C132, C133, C136, C138: 1uF; 0402
C129, C130: 10uF; 0402
C238, C239: 18pF; 0402
R53, R99, R100, R101, R102: 33R_1%; 0402
R60: 2.2k; 0402
R61: 4.87k_1%; 0402
R62: 1k; 0402
R63, R69, R70: DNI; 0402
R64, R65, R66, R67: 49.9R; 0402
R68: 0R; 0402
U14: Value; RHB0032B
U$7: ECS-250-18-36B-CKY-TR; OSCCC250X200X65
X1: J1006F01P; J1

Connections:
!ETH_INT: U14.8 (INT_PWDN_N); also elsewhere on the board
!ETH_RESET: U14.18 (RESET_N); also elsewhere on the board
ETH_LED_ACT: R69.2, R70.1, U14.17 (LED_0_AN_0_MLED), X1.12 (A-L)
ETH_LED_LINK: R62.1, R63.2, U14.24 (CLK_O), X1.9 (A-R)
ETH_MDC: U14.20 (MDC); also elsewhere on the board
ETH_MDIO: R60.1, U14.19 (MDIO); also elsewhere on the board
unnamed: R61.1, U14.16 (RBIAS)
unnamed: C238.2, U14.22 (XO), U$7.1 (XI)
unnamed: C239.2, R68.2, U$7.3 (XO)
unnamed: R66.1, U14.9 (RD_M), X1.8 (RD-)
unnamed: R67.1, U14.10 (RD_P), X1.7 (RD+)
unnamed: C135.1, C136.2, R64.2, R65.2
unnamed: R68.1, U14.23 (XI)
unnamed: C137.1, C138.2, R66.2, R67.2
unnamed: R65.1, U14.11 (TD_M), X1.2 (TD-)
unnamed: R64.1, U14.12 (TD_P), X1.1 (TD+)
unnamed: R53.2, U14.1 (RX_D3_PHYAD4_CLKOUT)
unnamed: R99.2, U14.32 (RX_D2_PHYAD3)
unnamed: R100.2, U14.31 (RX_D1_PHYAD2)
unnamed: R101.2, U14.30 (RX_D0_PHYAD1)
unnamed: R102.2, U14.25 (RX_CLK)
SOC_MII_COL_DET: U14.29 (COL_PHYAD0_MLED); also elsewhere on the board
SOC_MII_CRS: U14.27 (CRS_CRS_DV_LED_CFG); also elsewhere on the board
SOC_MII_RX0: R101.1; also elsewhere on the board
SOC_MII_RX1: R100.1; also elsewhere on the board
SOC_MII_RX2: R99.1; also elsewhere on the board
SOC_MII_RX3: R53.1; also elsewhere on the board
SOC_MII_RX_CLK: R102.1; also elsewhere on the board
SOC_MII_RX_DV: U14.26 (RX_DV_MII_MODE); also elsewhere on the board
SOC_MII_RX_ER: U14.28 (RX_ER_AMDIX_EN); also elsewhere on the board
SOC_MII_TX0: U14.4 (TX_D0); also elsewhere on the board
SOC_MII_TX1: U14.5 (TX_D1); also elsewhere on the board
SOC_MII_TX2: U14.6 (TX_D2); also elsewhere on the board
SOC_MII_TX3: U14.7 (TX_D3); also elsewhere on the board
SOC_MII_TX_CLK: U14.2 (TX_CLK); also elsewhere on the board
SOC_MII_TX_EN: U14.3 (TX_EN); also elsewhere on the board
VCC_3V3_IO: C123.2, C124.2, C125.2, C126.2, C127.2, C128.2, C129.2, C130.2, C131.2, C132.2, C133.2, C134.2, C135.2, C136.1, C137.2, C138.1, R60.2, R63.1, R70.2, U14.14 (AVD33), U14.21 (VDDIO), X1.3 (CT), X1.6 (CR); also elsewhere on the board
VSS: C123.1, C124.1, C125.1, C126.1, C127.1, C128.1, C129.1, C130.1, C131.1, C132.1, C133.1, C134.1, C238.1, C239.1, R61.2, R62.2, R69.1, U14.33 (PAD), U$7.2 (VSS), U$7.4 (VSS), X1.10 (C-R), X1.11 (C-L); also elsewhere on the board

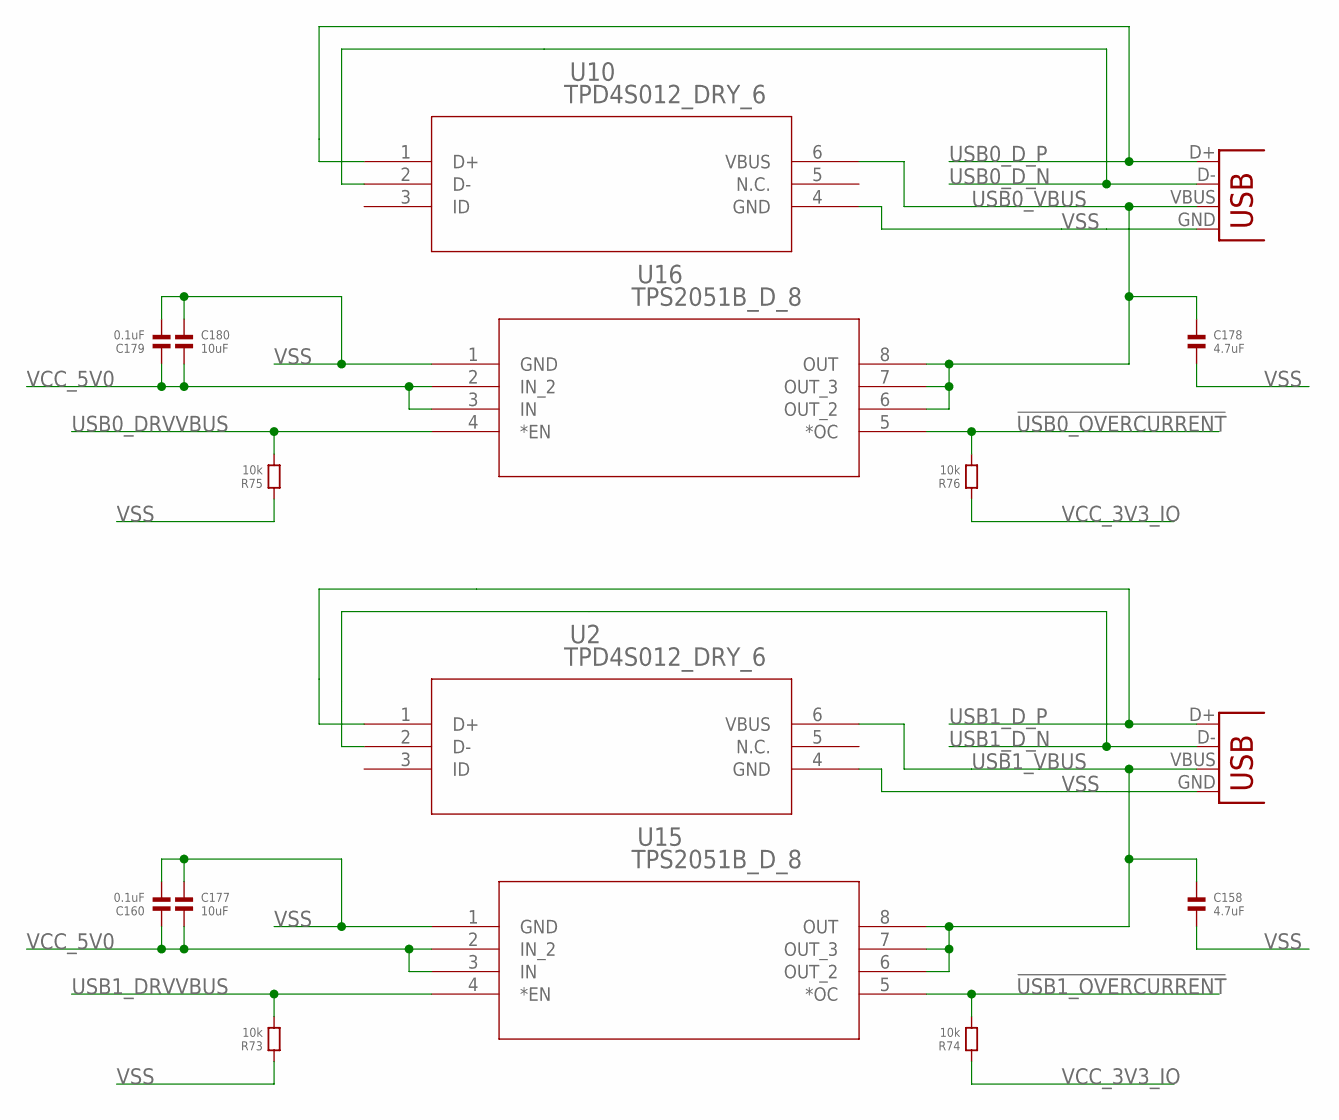
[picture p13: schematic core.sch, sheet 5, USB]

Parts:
C158, C178: 4.7uF; 0603
C160, C179: 0.1uF; 0603
C177, C180: 10uF; 0603
R73, R74, R75, R76: 10k; 0402
U2, U10: TPD4S012_DRY_6; DRY6
U15, U16: TPS2051B_D_8; D8
X2, X3: USB-A-H

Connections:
!USB0_OVERCURRENT: R76.2, U16.5 (*OC); also elsewhere on the board
!USB1_OVERCURRENT: R74.2, U15.5 (*OC); also elsewhere on the board
USB0_DRVVBUS: R75.2, U16.4 (*EN); also elsewhere on the board
USB0_D_N: U10.2 (D-), X3.D-; also elsewhere on the board
USB0_D_P: U10.1 (D+), X3.D+; also elsewhere on the board
USB0_VBUS: C178.1, U10.6 (VBUS), U16.6 (OUT_2), U16.7 (OUT_3), U16.8 (OUT), X3.VBUS; also elsewhere on the board
USB1_DRVVBUS: R73.2, U15.4 (*EN); also elsewhere on the board
USB1_D_N: U2.2 (D-), X2.D-; also elsewhere on the board
USB1_D_P: U2.1 (D+), X2.D+; also elsewhere on the board
USB1_VBUS: C158.1, U2.6 (VBUS), U15.6 (OUT_2), U15.7 (OUT_3), U15.8 (OUT), X2.VBUS; also elsewhere on the board
VCC_3V3_IO: R74.1, R76.1; also elsewhere on the board
VCC_5V0: C160.1, C177.2, C179.1, C180.2, U15.2 (IN_2), U15.3 (IN), U16.2 (IN_2), U16.3 (IN); also elsewhere on the board
VSS: C158.2, C160.2, C177.1, C178.2, C179.2, C180.1, R73.1, R75.1, U2.4 (GND), U10.4 (GND), U15.1 (GND), U16.1 (GND), X2.GND, X3.GND; also elsewhere on the board

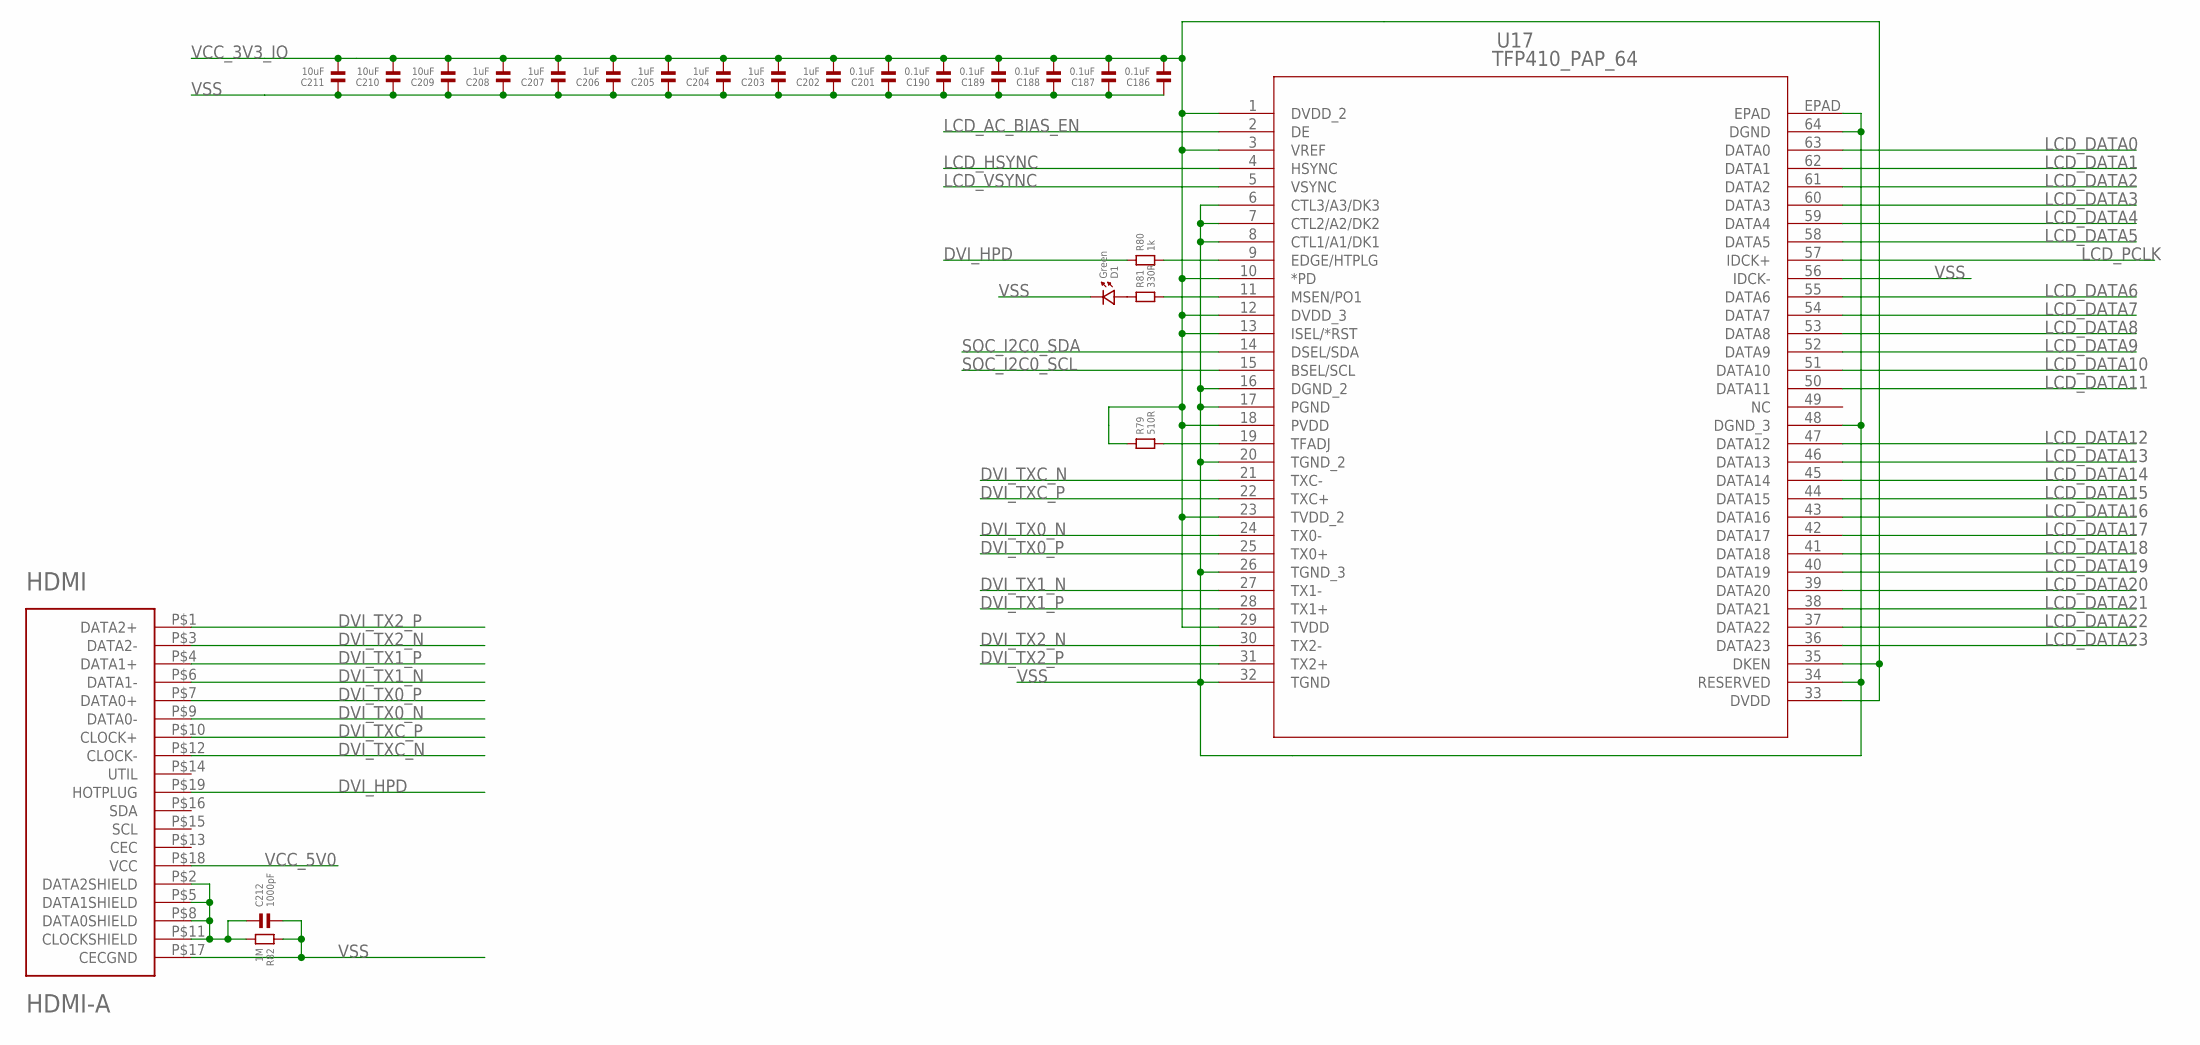
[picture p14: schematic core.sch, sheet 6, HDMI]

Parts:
C186, C187, C188, C189, C190, C201: 0.1uF; 0402
C202, C203, C204, C205, C206, C207, C208: 1uF; 0402
C209, C210, C211: 10uF; 0603
C212: 1000pF; 0402
D1: Green; 0603.LED
HDMI: HDMI-A; HDMI_A
R79: 510R; 0402
R80: 1k; 0402
R81: 330R; 0402
R82: 1M; 0402
U17: TFP410_PAP_64; PAP64_5X5

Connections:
DVI_HPD: HDMI.P$19 (HOTPLUG), R80.1
DVI_TX0_N: HDMI.P$9 (DATA0-), U17.24 (TX0-)
DVI_TX0_P: HDMI.P$7 (DATA0+), U17.25 (TX0+)
DVI_TX1_N: HDMI.P$6 (DATA1-), U17.27 (TX1-)
DVI_TX1_P: HDMI.P$4 (DATA1+), U17.28 (TX1+)
DVI_TX2_N: HDMI.P$3 (DATA2-), U17.30 (TX2-)
DVI_TX2_P: HDMI.P$1 (DATA2+), U17.31 (TX2+)
DVI_TXC_N: HDMI.P$12 (CLOCK-), U17.21 (TXC-)
DVI_TXC_P: HDMI.P$10 (CLOCK+), U17.22 (TXC+)
LCD_AC_BIAS_EN: U17.2 (DE); also elsewhere on the board
LCD_DATA0: U17.63 (DATA0); also elsewhere on the board
LCD_DATA1: U17.62 (DATA1); also elsewhere on the board
LCD_DATA2: U17.61 (DATA2); also elsewhere on the board
LCD_DATA3: U17.60 (DATA3); also elsewhere on the board
LCD_DATA4: U17.59 (DATA4); also elsewhere on the board
LCD_DATA5: U17.58 (DATA5); also elsewhere on the board
LCD_DATA6: U17.55 (DATA6); also elsewhere on the board
LCD_DATA7: U17.54 (DATA7); also elsewhere on the board
LCD_DATA8: U17.53 (DATA8); also elsewhere on the board
LCD_DATA9: U17.52 (DATA9); also elsewhere on the board
LCD_DATA10: U17.51 (DATA10); also elsewhere on the board
LCD_DATA11: U17.50 (DATA11); also elsewhere on the board
LCD_DATA12: U17.47 (DATA12); also elsewhere on the board
LCD_DATA13: U17.46 (DATA13); also elsewhere on the board
LCD_DATA14: U17.45 (DATA14); also elsewhere on the board
LCD_DATA15: U17.44 (DATA15); also elsewhere on the board
LCD_DATA16: U17.43 (DATA16); also elsewhere on the board
LCD_DATA17: U17.42 (DATA17); also elsewhere on the board
LCD_DATA18: U17.41 (DATA18); also elsewhere on the board
LCD_DATA19: U17.40 (DATA19); also elsewhere on the board
LCD_DATA20: U17.39 (DATA20); also elsewhere on the board
LCD_DATA21: U17.38 (DATA21); also elsewhere on the board
LCD_DATA22: U17.37 (DATA22); also elsewhere on the board
LCD_DATA23: U17.36 (DATA23); also elsewhere on the board
LCD_HSYNC: U17.4 (HSYNC); also elsewhere on the board
LCD_PCLK: U17.57 (IDCK+); also elsewhere on the board
LCD_VSYNC: U17.5 (VSYNC); also elsewhere on the board
unnamed: R79.2, U17.19 (TFADJ)
unnamed: R80.2, U17.9 (EDGE/HTPLG)
unnamed: R81.2, U17.11 (MSEN/PO1)
unnamed: D1.P$1 (1), R81.1
unnamed: C212.1, HDMI.P$2 (DATA2SHIELD), HDMI.P$5 (DATA1SHIELD), HDMI.P$8 (DATA0SHIELD), HDMI.P$11 (CLOCKSHIELD), R82.2
SOC_I2C0_SCL: U17.15 (BSEL/SCL); also elsewhere on the board
SOC_I2C0_SDA: U17.14 (DSEL/SDA); also elsewhere on the board
VCC_3V3_IO: C186.2, C187.2, C188.2, C189.2, C190.2, C201.2, C202.2, C203.2, C204.2, C205.2, C206.2, C207.2, C208.2, C209.2, C210.2, C211.2, R79.1, U17.1 (DVDD_2), U17.3 (VREF), U17.10 (*PD), U17.12 (DVDD_3), U17.13 (ISEL/*RST), U17.18 (PVDD), U17.23 (TVDD_2), U17.29 (TVDD), U17.33 (DVDD), U17.35 (DKEN); also elsewhere on the board
VCC_5V0: HDMI.P$18 (VCC); also elsewhere on the board
VSS: C186.1, C187.1, C188.1, C189.1, C190.1, C201.1, C202.1, C203.1, C204.1, C205.1, C206.1, C207.1, C208.1, C209.1, C210.1, C211.1, C212.2, D1.P$2 (2), HDMI.P$17 (CECGND), R82.1, U17.6 (CTL3/A3/DK3), U17.7 (CTL2/A2/DK2), U17.8 (CTL1/A1/DK1), U17.16 (DGND_2), U17.17 (PGND), U17.20 (TGND_2), U17.26 (TGND_3), U17.32 (TGND), U17.34 (RESERVED), U17.48 (DGND_3), U17.56 (IDCK-), U17.64 (DGND), U17.EPAD; also elsewhere on the board

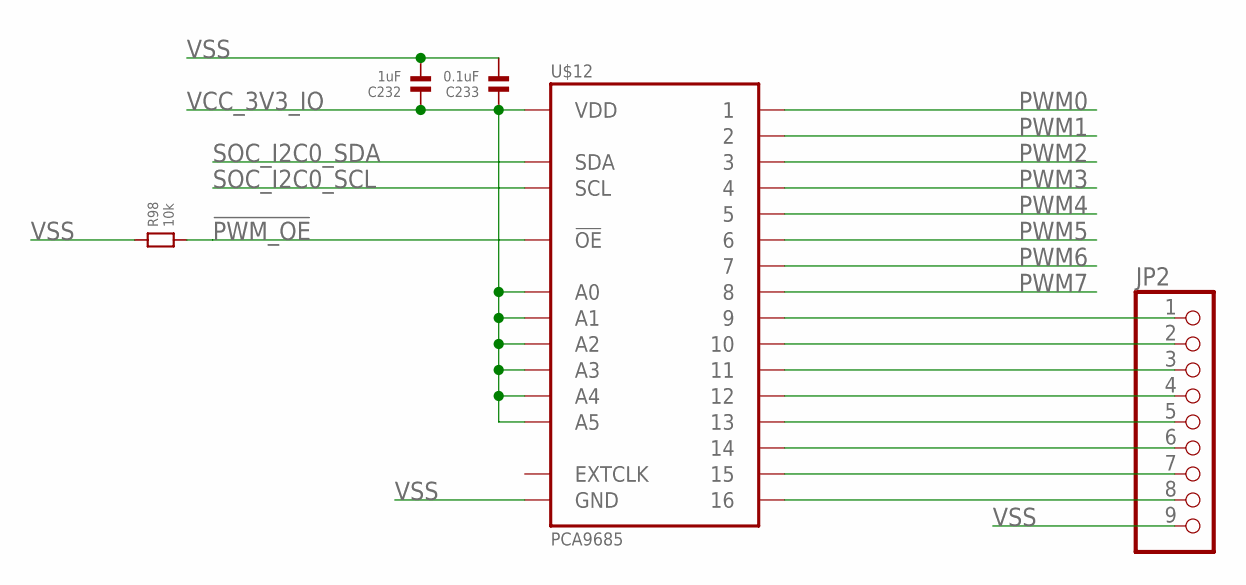
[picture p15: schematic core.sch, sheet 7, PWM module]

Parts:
C232: 1uF; 0402
C233: 0.1uF; 0402
JP2: PINHD-1X9; 1X09
R98: 10k; 0402
U$12: PCA9685; HVQFN28

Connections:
!PWM_OE: R98.2, U$12.23 (!OE)
unnamed: JP2.1, U$12.15 (9)
unnamed: JP2.2, U$12.16 (10)
unnamed: JP2.3, U$12.17 (11)
unnamed: JP2.5, U$12.19 (13)
unnamed: JP2.4, U$12.18 (12)
unnamed: JP2.6, U$12.20 (14)
unnamed: JP2.7, U$12.21 (15)
unnamed: JP2.8, U$12.22 (16)
PWM0: U$12.6 (1); also elsewhere on the board
PWM1: U$12.7 (2); also elsewhere on the board
PWM2: U$12.8 (3); also elsewhere on the board
PWM3: U$12.9 (4); also elsewhere on the board
PWM4: U$12.10 (5); also elsewhere on the board
PWM5: U$12.11 (6); also elsewhere on the board
PWM6: U$12.12 (7); also elsewhere on the board
PWM7: U$12.13 (8); also elsewhere on the board
SOC_I2C0_SCL: U$12.26 (SCL); also elsewhere on the board
SOC_I2C0_SDA: U$12.27 (SDA); also elsewhere on the board
VCC_3V3_IO: C232.1, C233.1, U$12.1 (A0), U$12.2 (A1), U$12.3 (A2), U$12.4 (A3), U$12.5 (A4), U$12.24 (A5), U$12.28 (VDD); also elsewhere on the board
VSS: C232.2, C233.2, JP2.9, R98.1, U$12.14 (GND), U$12.PAD (GND); also elsewhere on the board

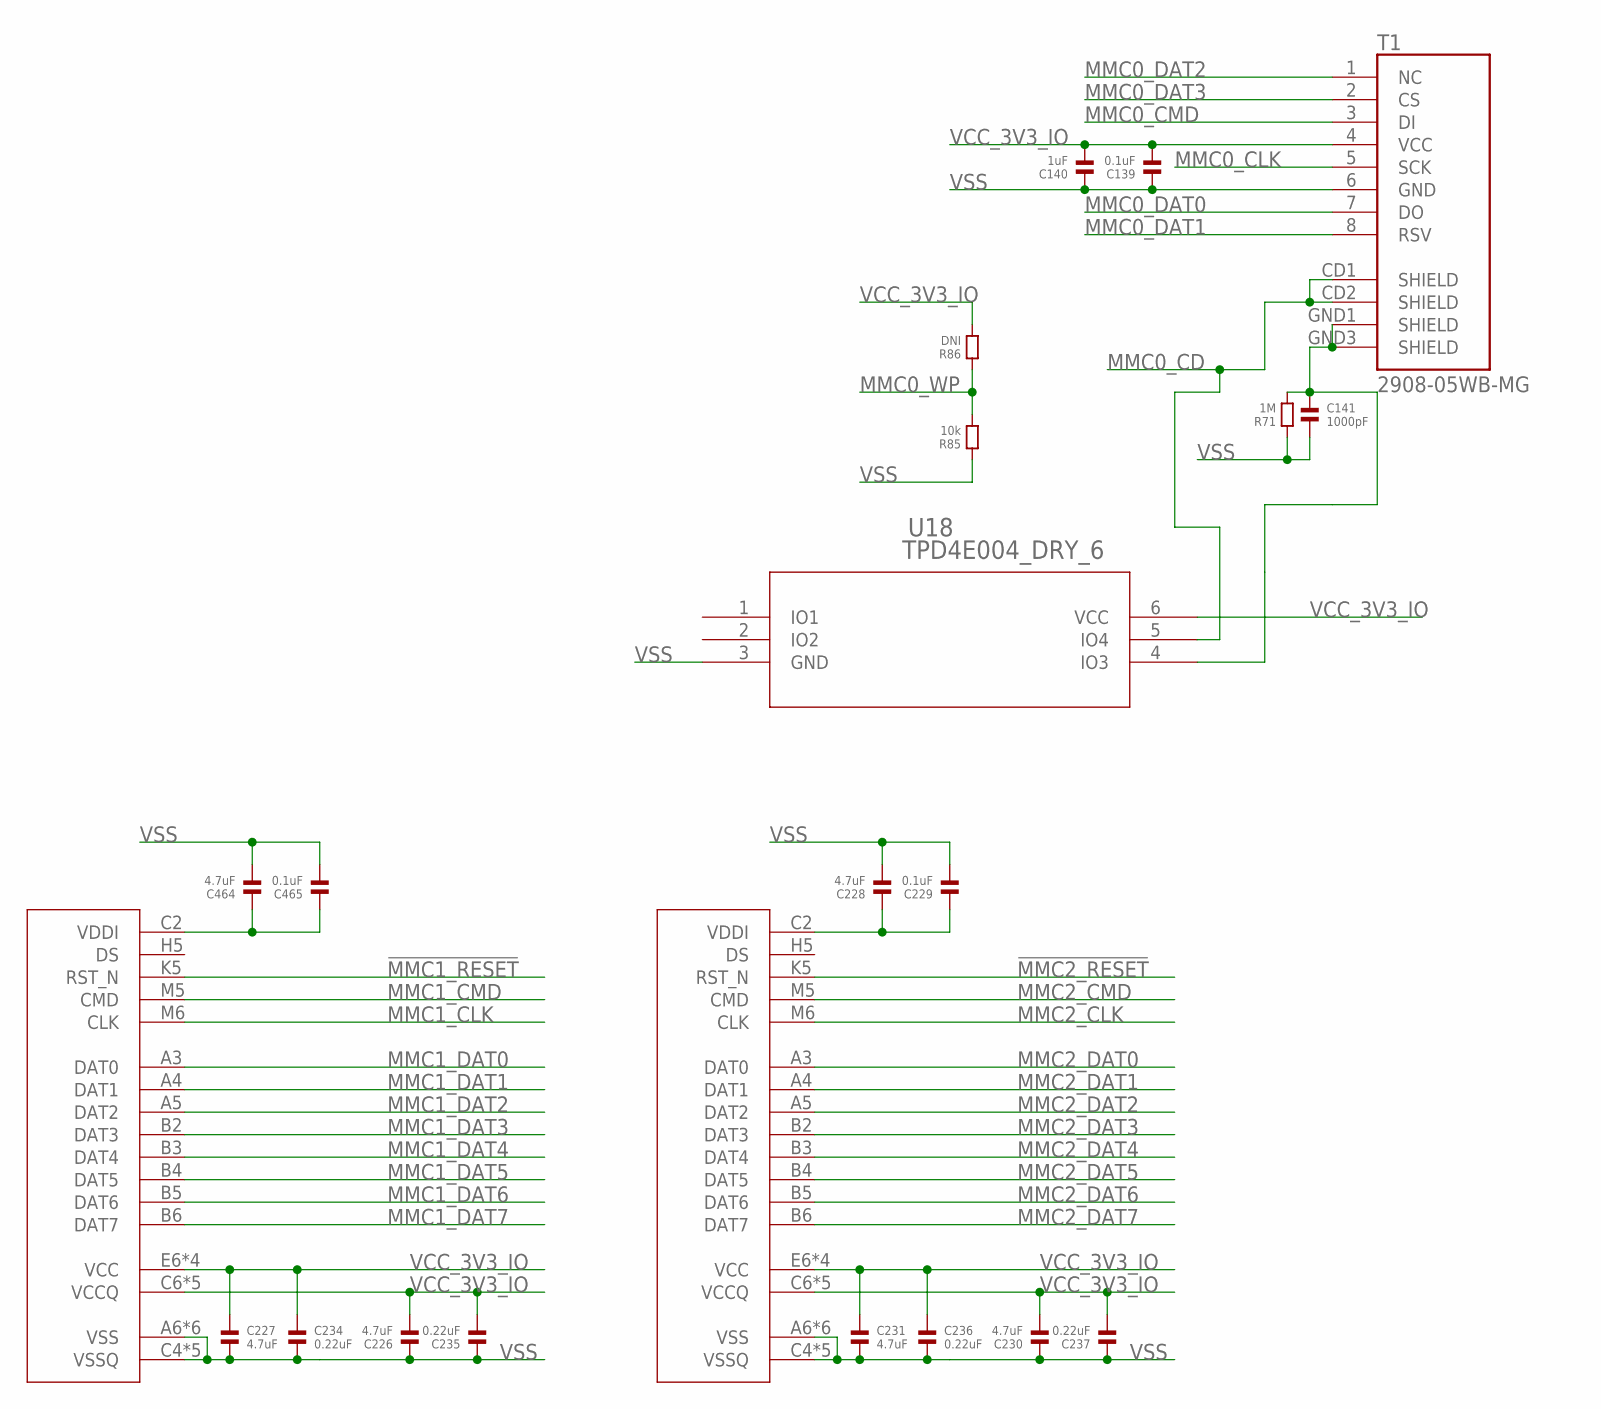
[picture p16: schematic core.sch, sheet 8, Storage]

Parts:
C139: 0.1uF; 0402
C140: 1uF; 0402
C141: 1000pF; 0402
C226, C227, C228, C230, C231, C464: 4.7uF; 0603
C229, C465: 0.1uF; 0603
C234, C235, C236, C237: 0.22uF; 0603
R71: 1M; 0402
R85: 10k; 0402
R86: DNI; 0402
T1: 2908-05WB-MG; MICRO-SD-SOCKET-PP
U18: TPD4E004_DRY_6; DRY6
U$10, U$11: IS21ES16G; BGA153C50P14X14_1150X1300X100N

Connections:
!MMC1_RESET: U$10.K5 (RST_N); also elsewhere on the board
!MMC2_RESET: U$11.K5 (RST_N); also elsewhere on the board
MMC0_CD: T1.CD1 (SHIELD), T1.CD2 (SHIELD), U18.5 (IO4); also elsewhere on the board
MMC0_CLK: T1.5 (SCK); also elsewhere on the board
MMC0_CMD: T1.3 (DI); also elsewhere on the board
MMC0_DAT0: T1.7 (DO); also elsewhere on the board
MMC0_DAT1: T1.8 (RSV); also elsewhere on the board
MMC0_DAT2: T1.1 (NC); also elsewhere on the board
MMC0_DAT3: T1.2 (CS); also elsewhere on the board
MMC0_WP: R85.2, R86.1; also elsewhere on the board
MMC1_CLK: U$10.M6 (CLK); also elsewhere on the board
MMC1_CMD: U$10.M5 (CMD); also elsewhere on the board
MMC1_DAT0: U$10.A3 (DAT0); also elsewhere on the board
MMC1_DAT1: U$10.A4 (DAT1); also elsewhere on the board
MMC1_DAT2: U$10.A5 (DAT2); also elsewhere on the board
MMC1_DAT3: U$10.B2 (DAT3); also elsewhere on the board
MMC1_DAT4: U$10.B3 (DAT4); also elsewhere on the board
MMC1_DAT5: U$10.B4 (DAT5); also elsewhere on the board
MMC1_DAT6: U$10.B5 (DAT6); also elsewhere on the board
MMC1_DAT7: U$10.B6 (DAT7); also elsewhere on the board
MMC2_CLK: U$11.M6 (CLK); also elsewhere on the board
MMC2_CMD: U$11.M5 (CMD); also elsewhere on the board
MMC2_DAT0: U$11.A3 (DAT0); also elsewhere on the board
MMC2_DAT1: U$11.A4 (DAT1); also elsewhere on the board
MMC2_DAT2: U$11.A5 (DAT2); also elsewhere on the board
MMC2_DAT3: U$11.B2 (DAT3); also elsewhere on the board
MMC2_DAT4: U$11.B3 (DAT4); also elsewhere on the board
MMC2_DAT5: U$11.B4 (DAT5); also elsewhere on the board
MMC2_DAT6: U$11.B5 (DAT6); also elsewhere on the board
MMC2_DAT7: U$11.B6 (DAT7); also elsewhere on the board
unnamed: C141.1, R71.2, T1.GND1 (SHIELD), T1.GND3 (SHIELD), U18.4 (IO3)
unnamed: C464.1, C465.1, U$10.C2 (VDDI)
unnamed: C228.1, C229.1, U$11.C2 (VDDI)
VCC_3V3_IO: C139.2, C140.2, C226.2, C227.1, C230.2, C231.1, C234.1, C235.2, C236.1, C237.2, R86.2, T1.4 (VCC), U18.6 (VCC), U$10.C6 (VCCQ), U$10.E6 (VCC), U$10.F5 (VCC), U$10.J10 (VCC), U$10.K9 (VCC), U$10.M4 (VCCQ), U$10.N4 (VCCQ), U$10.P3 (VCCQ), U$10.P5 (VCCQ), U$11.C6 (VCCQ), U$11.E6 (VCC), U$11.F5 (VCC), U$11.J10 (VCC), U$11.K9 (VCC), U$11.M4 (VCCQ), U$11.N4 (VCCQ), U$11.P3 (VCCQ), U$11.P5 (VCCQ); also elsewhere on the board
VSS: C139.1, C140.1, C141.2, C226.1, C227.2, C228.2, C229.2, C230.1, C231.2, C234.2, C235.1, C236.2, C237.1, C464.2, C465.2, R71.1, R85.1, T1.6 (GND), U18.3 (GND), U$10.A6 (VSS), U$10.C4 (VSSQ), U$10.E7 (VSS), U$10.G5 (VSS), U$10.H10 (VSS), U$10.J5 (VSS), U$10.K8 (VSS), U$10.N2 (VSSQ), U$10.N5 (VSSQ), U$10.P4 (VSSQ), U$10.P6 (VSSQ), U$11.A6 (VSS), U$11.C4 (VSSQ), U$11.E7 (VSS), U$11.G5 (VSS), U$11.H10 (VSS), U$11.J5 (VSS), U$11.K8 (VSS), U$11.N2 (VSSQ), U$11.N5 (VSSQ), U$11.P4 (VSSQ), U$11.P6 (VSSQ); also elsewhere on the board

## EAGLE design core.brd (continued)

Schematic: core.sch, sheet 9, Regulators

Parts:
C4, C36, C37, C38, C42, C43, C162, C175, C181: 10uF; 0603
C5, C7, C8, C12, C46, C47, C87, C152, C153, C164, C182, C184, C185, C192, C195: 0.1uF; 0603
C6, C176, C183, C198, C199: 22uF; 0603
C34, C35: 150uF; CAPPRD350W65D800H1500B
C39, C40: 1nF; 0603
C41, C45, C148, C149: 4.7uF; 0603
C44: 0.033uF; 0603
C86, C151, C163, C191: 1uF; 0603
C142, C145: 470uF; CAPPRD300W65D800H1200B
C143, C144: 270uF; CAPPRD350W65D800H1500B
C146: 220uF; CAPPRD250W65D600H1100B
C150, C167: 0.47uF; 0603
C154, C172: 100pF; 0603
C155, C165, C173: 0.01uF; 0603
C156, C171: 0.056uF; 0603
C157, C161, C174: 47uF; 0805
C159: 100uF; 0805
C166, C168: 2.2uF; 0603
C169, C170: 33pF; 0603
C193: 10uF; 0805
C194: 0.1uF; 0805
C196: 0.015uF; 0603
C197: 150pF; 0603
C200: 200pF; 0603
C216: DNI; 0603
D5, D6: Green; 0603.LED
Q8, Q9, Q10, Q11: CSD18543Q3A; SON65P300X315X90-9N
R13: 5.11R; 0603
R14: 7.15k; 0603
R15, R208, R230, R243: 100k; 0603
R16: 0.006R; 0805
R17: 3.09R; 0603
R18: DNI; 0603
R19, R20: 4.75k; 0603
R52, R229: 10k; 0603
R54: 4.7k; 0603
R202, R203, R204, R211, R212, R213: 10.2R; 0603
R205, R217: 0.005R; R2512
R206: 0R; 0603
R207: 19.6k 0.1%; 0603
R214, R215, R216: 49.9R; 0603
R218: 29.4k 1%; 0603
R219: 220R; 0603
R220: 330R; 0603
R231: 2.05k_1%; 0603
R232: 51.1R_1%; 0603
R233: 31.6k_1%; 0603
R234: 10k_1%; 0603
TP1, TP2, TP24, TP25, TP26, TP29, TP31, TP32: TESTPAD_TPSQB1,27; TESTPAD_B1,27
U4, U38: Value; YZH0016AFAF
U6: TPS51116_PWP_20; PWP20_3P4X2P4
U11, U40: Value; DRV0006A
U34: Value; RWG0040A
U35: Value; RLT0007A
U41: Value; DRC0010J
U$1, U$28, U$30: XFL4015-471MEB
U$2: IRF7821; SOIC127P600X175-8_V2
U$3: IRF7832; SOIC127P600X175-8_V2
U$4: XFL4020-102MEB
U$20, U$21: DB2441700L
U$22, U$25: XEL6030-152MEB
U$33: XEL4030-682ME_

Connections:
DDR_VREF: C44.2, U6.7 (VTTREF); also elsewhere on the board
DDR_VTT: C42.2, C43.2, U6.2 (VTT), U6.4 (VTTSNS); also elsewhere on the board
unnamed: U4.B3 (SW_2), U4.B4 (SW), U$1.P$1
unnamed: R19.1, R20.2, U6.10 (VDDQSET)
unnamed: C12.1, U6.20 (VBST)
unnamed: U6.17 (DRVL), U$3.4 (GATE)
unnamed: R13.1, U6.19 (DRVH)
unnamed: R13.2, U$2.4 (GATE)
unnamed: C12.2, U6.18 (LL), U$2.1 (SOURCE), U$2.2 (SOURCE), U$2.3 (SOURCE), U$3.5 (DRAIN), U$3.6 (DRAIN), U$3.7 (DRAIN), U$3.8 (DRAIN), U$4.V
unnamed: C39.2, R14.1, U6.15 (CS)
unnamed: C40.1, R16.2, R18.2, U$3.1 (SOURCE), U$3.2 (SOURCE), U$3.3 (SOURCE)
unnamed: C40.2, R17.1
unnamed: C151.2, U34.32 (RES)
unnamed: C152.1, U34.20 (HB1), U$21.CATHODE
unnamed: C153.2, U34.11 (HB2), U$20.CATHODE
unnamed: C152.2, Q8.1 (S), Q8.2 (S), Q8.3 (S), Q9.5-9 (D), U34.21 (SW1), U$22.P$2
unnamed: Q8.4 (G), R202.1, U34.23 (HOL1)
unnamed: R202.2, U34.22 (HO1)
unnamed: Q9.4 (G), R203.1, R204.1
unnamed: R203.2, U34.18 (LO1)
unnamed: R204.2, U34.19 (LOL1)
unnamed: R205.2, R214.2, U$22.P$1
unnamed: C169.1, R214.1, U34.27 (CS1)
unnamed: C169.2, R206.1, U34.26 (VOUT1)
unnamed: C154.2, R207.2, U34.29 (COMP1)
unnamed: C155.2, R207.1
unnamed: C156.2, U34.30 (SS1)
unnamed: C153.1, Q10.5-9 (D), Q11.1 (S), Q11.2 (S), Q11.3 (S), U34.10 (SW2), U$25.P$1
unnamed: Q11.4 (G), R211.1, U34.8 (HOL2)
unnamed: R211.2, U34.9 (HO2)
unnamed: R212.1, U34.12 (LOL2)
unnamed: R213.1, U34.13 (LO2)
unnamed: Q10.4 (G), R212.2, R213.2
unnamed: R215.2, R217.1, U$25.P$2
unnamed: C170.2, R215.1, U34.4 (CS2)
unnamed: C170.1, R216.1, U34.5 (VOUT2)
unnamed: C171.2, U34.1 (SS2)
unnamed: C173.1, R218.2
unnamed: C172.1, R218.1, U34.2 (COMP2)
unnamed: D6.P$1 (1), R219.2
unnamed: D5.P$1 (1), R220.2
unnamed: U35.6 (SW), U$28.P$1
unnamed: U38.B3 (SW_2), U38.B4 (SW), U$30.P$1
unnamed: C195.2, U41.2 (PH), U$33.P$1
unnamed: C195.1, U41.9 (BOOT)
unnamed: C196.1, R231.2
unnamed: C197.1, R231.1, U41.7 (COMP)
unnamed: C200.2, R232.1, R233.2
RESET_SOC_MPU: C8.1, C185.1, U4.D1 (VDD), U38.D1 (VDD); also elsewhere on the board
SOC_CORE: C183.2, C184.2, TP29.TP, U$30.P$2; also elsewhere on the board
SOC_I2C0_SCL: U38.D3 (SCL); also elsewhere on the board
SOC_I2C0_SDA: U38.D2 (SDA); also elsewhere on the board
SOC_I2C2_SCL: U4.D3 (SCL); also elsewhere on the board
SOC_I2C2_SDA: U4.D2 (SDA); also elsewhere on the board
SOC_MPU: C6.2, C7.2, TP1.TP, U$1.P$2; also elsewhere on the board
TPS54334_VSENSE: C200.1, R233.1, R234.2, U41.6 (VSENSE)
VCC_1V5_DDR: C34.1 (+), C35.1 (+), C38.2, R17.2, R19.2, U6.1 (VLDOIN), U6.6 (MODE), U6.9 (VDDQSNS), U$4.V1; also elsewhere on the board
VCC_1V8: C176.2, TP26.TP, U35.3 (FB), U35.4 (VOS), U$28.P$2; also elsewhere on the board
VCC_1V8_PG: R54.1, U6.11 (S3), U6.12 (S5), U35.2 (PG)
VCC_3V3_IO: C198.2, C199.2, R232.2, TP32.TP, U$33.P$2; also elsewhere on the board
VCC_3V3_PREREG: C4.2, C5.2, C142.1 (+), C143.1 (+), C157.2, C175.2, C181.2, C182.2, R52.2, R54.2, R205.1, R206.2, R208.2, R219.1, R229.2, R230.2, TP24.TP, U4.A1 (AVIN), U4.A3 (VSEL1), U4.A4 (VIN), U4.C2 (VSEL0), U11.6 (IN), U35.7 (VIN), U38.A1 (AVIN), U38.A3 (VSEL1), U38.A4 (VIN), U38.C2 (VSEL0), U40.6 (IN); also elsewhere on the board
VCC_3V3_PREREG_PG: C165.2, R208.1, U34.24 (PG1)
VCC_5V0: C39.1, C41.2, C45.2, C46.2, C47.2, C144.1 (+), C145.1 (+), C174.2, R14.2, R15.2, R216.2, R217.2, R220.1, TP25.TP, U6.8 (COMP), U6.14 (V5IN), U34.6 (VCCX); also elsewhere on the board
VCC_5V0_PG: R243.2, U34.7 (PG2)
VCC_12V0: C36.2, C37.2, C146.1 (+), C159.2, C161.2, C162.2, C163.2, C164.2, C166.1, C167.1, C168.1, C193.2, C194.2, Q8.5-9 (D), Q11.5-9 (D), U34.25 (VIN), U34.31 (EN1), U34.40 (EN2), U41.1 (VIN), U$2.5 (DRAIN), U$2.6 (DRAIN), U$2.7 (DRAIN), U$2.8 (DRAIN); also elsewhere on the board
VCC_LM5140: C148.2, C149.2, U34.15 (VCC_2), U34.16 (VCC), U$20.ANODE, U$21.ANODE
VDDA_1V8: C191.1, TP31.TP, U40.1 (OUT); also elsewhere on the board
VDDA_1V8_PG: C192.1, R229.1, U40.3 (PG)
VDDA_LM5140: C150.1, R243.1, U34.3 (FB2), U34.28 (FB1), U34.33 (DEMB), U34.34 (ILSET), U34.36 (VDDA), U34.37 (OSC)
VDDS_DDR_PGOOD: R15.1, U6.13 (PGOOD), U41.8 (EN)
VDD_CORE: U38.B1 (SENSE+); also elsewhere on the board
VDD_MPU: U4.B1 (SENSE+); also elsewhere on the board
VDD_RTC: C86.1, TP2.TP, U11.1 (OUT); also elsewhere on the board
VDD_RTC_PG: C87.1, R52.1, U11.3 (PG), U35.1 (EN), U40.4 (EN)
VIN_MON_PORZ_3V3_PG: C216.2, R230.1, U4.B2 (EN), U11.4 (EN), U38.B2 (EN), U41.10 (PGOOD); also elsewhere on the board
VSS: C4.1, C5.1, C6.1, C7.1, C8.2, C34.2 (-), C35.2 (-), C36.1, C37.1, C38.1, C41.1, C42.1, C43.1, C44.1, C45.1, C46.1, C47.1, C86.2, C87.2, C142.2 (-), C143.2 (-), C144.2 (-), C145.2 (-), C146.2 (-), C148.1, C149.1, C150.2, C151.1, C154.1, C155.1, C156.1, C157.1, C159.1, C161.1, C162.1, C163.1, C164.1, C165.1, C166.2, C167.2, C168.2, C171.1, C172.2, C173.2, C174.1, C175.1, C176.1, C181.1, C182.1, C183.1, C184.1, C185.2, C191.2, C192.2, C193.1, C194.1, C196.2, C197.2, C198.1, C199.1, C216.1, D5.P$2 (2), D6.P$2 (2), Q9.1 (S), Q9.2 (S), Q9.3 (S), Q10.1 (S), Q10.2 (S), Q10.3 (S), R16.1, R18.1, R20.1, R234.1, U4.A2 (AGND), U4.C1 (SENSE-), U4.C3 (PGND_2), U4.C4 (PGND_3), U4.D4 (PGND), U6.3 (VTTGND), U6.5 (GND), U6.16 (PGND), U6.21 (EPAD), U11.5 (GND), U11.7 (PAD), U34.14 (PGND2), U34.17 (PGND1), U34.35 (AGND), U34.38 (SYN_IN), U34.41 (DAP), U35.5 (GND), U38.A2 (AGND), U38.C1 (SENSE-), U38.C3 (PGND_2), U38.C4 (PGND_3), U38.D4 (PGND), U40.5 (GND), U40.7 (PAD), U41.3 (GND_2), U41.4 (GND_3), U41.5 (GND), U41.11 (PAD); also elsewhere on the board

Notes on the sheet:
TPS62363
TPS62087
LM5140
TPS54334
LP5912

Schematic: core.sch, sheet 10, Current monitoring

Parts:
C1, C2, C3, C9, C10, C11, C13, C29, C30, C31, C32, C33: 0.1uF; 0603
R1, R2, R4, R5, R7, R8, R10, R11: 10_1%; 0603
R3, R6, R9, R12: 0.002_1%; 1206
U3, U5, U7, U8: INA226_DGS_10; DGS10

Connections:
INA_ALERT: U3.3 (ALERT), U5.3 (ALERT), U7.3 (ALERT), U8.3 (ALERT); also elsewhere on the board
unnamed: C2.2, R2.1, U3.8 (VBUS), U3.9 (VIN-)
unnamed: C2.1, R1.1, U3.10 (VIN+)
unnamed: C10.2, R5.1, U5.8 (VBUS), U5.9 (VIN-)
unnamed: C10.1, R4.1, U5.10 (VIN+)
unnamed: C29.2, R8.1, U7.8 (VBUS), U7.9 (VIN-)
unnamed: C29.1, R7.1, U7.10 (VIN+)
unnamed: C32.2, R11.1, U8.8 (VBUS), U8.9 (VIN-)
unnamed: C32.1, R10.1, U8.10 (VIN+)
SOC_CORE: C3.1, R1.2, R3.1; also elsewhere on the board
SOC_I2C0_SCL: U3.5 (SCL), U5.5 (SCL), U7.5 (SCL), U8.2 (A0), U8.5 (SCL); also elsewhere on the board
SOC_I2C0_SDA: U3.4 (SDA), U5.4 (SDA), U7.2 (A0), U7.4 (SDA), U8.4 (SDA); also elsewhere on the board
SOC_MPU: C11.1, R4.2, R6.1; also elsewhere on the board
SOC_VDDS_DDR: R11.2, R12.2; also elsewhere on the board
VCC_1V5_DDR: C30.1, C33.1, R7.2, R9.1, R10.2, R12.1; also elsewhere on the board
VCC_3V3_IO: C1.2, C9.2, C13.2, C31.2, U3.6 (VS), U5.1 (A1), U5.6 (VS), U7.6 (VS), U8.6 (VS); also elsewhere on the board
VDDS_DDR: R8.2, R9.2; also elsewhere on the board
VDD_CORE: R2.2, R3.2; also elsewhere on the board
VDD_MPU: R5.2, R6.2; also elsewhere on the board
VSS: C1.1, C3.2, C9.1, C11.2, C13.1, C30.2, C31.1, C33.2, U3.1 (A1), U3.2 (A0), U3.7 (GND), U5.2 (A0), U5.7 (GND), U7.1 (A1), U7.7 (GND), U8.1 (A1), U8.7 (GND); also elsewhere on the board

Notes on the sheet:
I2C Address=0x40
I2C Address=0x41
I2C Address=0x42
I2C Address=0x43

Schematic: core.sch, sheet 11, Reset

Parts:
C574, C578, C579: 0.1uF; 0402
C575: 0.01uF; 0402
C577: DNI; 0402
R72: 1k; 0402
R536: 261k_1%; 0402
R537, R538, R541, R542: 10k_1%; 0402
R540: 5.81k_1%; 0402
R543: 0R; 0402
TP14: TESTPAD_TPSQB1,27; TESTPAD_B1,27
U76: Value; DDC0006A_N
U77: TPS3897_DRY_6; DRY6
U78: SN74LVC1G11_DCK_6; DCK6

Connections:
!JTAG_TRST: U78.6 (C); also elsewhere on the board
!SUPERVISOR_MASTER_RESET: R72.1, U77.1 (ENABLE); also elsewhere on the board
unnamed: C575.1, R536.1, R537.2, U76.3 (SENSE)
unnamed: C577.1, U77.5 (CT)
unnamed: R543.1, U78.4 (Y)
unnamed: R540.1, R541.2, U77.3 (SENSE)
SOC_PORZ: R543.2, TP14.TP; also elsewhere on the board
SOC_POWER_MON_PORZ: R542.1, U77.4 (SENSE_OUT), U78.1 (A)
VCC_3V3_IO: C579.1, R538.2, R542.2, U78.5 (VCC); also elsewhere on the board
VCC_3V3_PREREG: C578.2, R72.2, U77.6 (VCC); also elsewhere on the board
VCC_12V0: C574.2, R536.2, U76.5 (VDD); also elsewhere on the board
VDD_MPU: R540.2; also elsewhere on the board
VIN_MON_PORZ_3V3_PG: R538.1, U76.1 (OUT), U78.3 (B); also elsewhere on the board
VSS: C574.1, C575.2, C577.2, C578.1, C579.2, R537.1, R541.1, U76.2 (GND_2), U76.4 (GND_3), U76.6 (GND), U77.2 (GND), U78.2 (GND); also elsewhere on the board

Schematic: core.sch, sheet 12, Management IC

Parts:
C117: 0.1uF; 0402
R55, R90, R91, R94, R95, R96, R97: 10k; 0402
U12: TCA9555_RTW_24; RTW24_2P45X2P45

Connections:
!ETH_INT: R90.2, U12.2 (P01); also elsewhere on the board
!ETH_RESET: R91.2, U12.3 (P02); also elsewhere on the board
!MGMT_INT0: R94.2, U12.7 (P06); also elsewhere on the board
!MGMT_INT1: R95.2, U12.8 (P07); also elsewhere on the board
!MMC1_RESET: R97.2, U12.12; also elsewhere on the board
!MMC2_RESET: R96.2, U12.11; also elsewhere on the board
!NMI: R55.1, U12.22 (*INT); also elsewhere on the board
!USB0_OVERCURRENT: U12.4 (P03); also elsewhere on the board
!USB1_OVERCURRENT: U12.5 (P04); also elsewhere on the board
DCAN1_STB: U12.6 (P05); also elsewhere on the board
EXT_WAKEUP: U12.10; also elsewhere on the board
INA_ALERT: U12.1 (P00); also elsewhere on the board
RESET_SOC_MPU: U12.17; also elsewhere on the board
SOC_I2C0_SCL: U12.19 (SCL); also elsewhere on the board
SOC_I2C0_SDA: U12.20 (SDA); also elsewhere on the board
VCC_3V3_IO: C117.2, R55.2, R90.1, R91.1, R94.1, R95.1, R96.1, R97.1, U12.21 (VCC); also elsewhere on the board
VSS: C117.1, U12.9 (GND), U12.18 (A0), U12.23 (A1), U12.24 (A2), U12.25 (EPAD); also elsewhere on the board

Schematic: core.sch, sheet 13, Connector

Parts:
C147: 470uF; CAPPRD300W65D800H1200B
J1: SEAM-40-XX.X-XX-06-X-A

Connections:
!MGMT_INT0: J1.B26 (26); also elsewhere on the board
!MGMT_INT1: J1.B25 (25); also elsewhere on the board
!SUPERVISOR_MASTER_RESET: J1.B19 (19); also elsewhere on the board
!UART1_CTS: J1.C26 (26); also elsewhere on the board
!UART1_RTS: J1.C25 (25); also elsewhere on the board
!WARM_RESET: J1.C6 (6); also elsewhere on the board
DCAN1_H: J1.B17 (17); also elsewhere on the board
DCAN1_L: J1.B16 (16); also elsewhere on the board
EXT_WAKEUP: J1.C7 (7); also elsewhere on the board
GPIO1_16: J1.C17 (17); also elsewhere on the board
GPIO1_20: J1.C18 (18); also elsewhere on the board
GPIO1_21: J1.C19 (19); also elsewhere on the board
GPIO1_26: J1.C20 (20); also elsewhere on the board
GPIO1_27: J1.C21 (21); also elsewhere on the board
GPIO1_29: J1.C10 (10); also elsewhere on the board
GPIO2_4: J1.C9 (9); also elsewhere on the board
GPIO3_7: J1.C16 (16); also elsewhere on the board
GPIO3_8: J1.C15 (15); also elsewhere on the board
GPIO3_18: J1.C11 (11); also elsewhere on the board
GPIO3_19: J1.C12 (12); also elsewhere on the board
GPIO3_20: J1.C13 (13); also elsewhere on the board
GPIO3_21: J1.C14 (14); also elsewhere on the board
PWM0: J1.A30 (30); also elsewhere on the board
PWM1: J1.A31 (31); also elsewhere on the board
PWM2: J1.A32 (32); also elsewhere on the board
PWM3: J1.A33 (33); also elsewhere on the board
PWM4: J1.A34 (34); also elsewhere on the board
PWM5: J1.A35 (35); also elsewhere on the board
PWM6: J1.A36 (36); also elsewhere on the board
PWM7: J1.A37 (37); also elsewhere on the board
SOC_I2C2_SCL: J1.A40 (40); also elsewhere on the board
SOC_I2C2_SDA: J1.A39 (39); also elsewhere on the board
SPI0_CLK: J1.B12 (12); also elsewhere on the board
SPI0_CS0: J1.B13 (13); also elsewhere on the board
SPI0_MISO: J1.B14 (14); also elsewhere on the board
SPI0_MOSI: J1.B11 (11); also elsewhere on the board
SPI1_CLK: J1.C29 (29); also elsewhere on the board
SPI1_CS0: J1.C31 (31); also elsewhere on the board
SPI1_D0: J1.C30 (30); also elsewhere on the board
SPI1_D1: J1.C28 (28); also elsewhere on the board
TIMER4: J1.C1 (1); also elsewhere on the board
TIMER5: J1.C2 (2); also elsewhere on the board
TIMER6: J1.C3 (3); also elsewhere on the board
TIMER7: J1.C4 (4); also elsewhere on the board
UART1_RXD: J1.C24 (24); also elsewhere on the board
UART1_TXD: J1.C23 (23); also elsewhere on the board
VCC_3V3_IO: J1.B23 (23); also elsewhere on the board
VCC_5V0: J1.B21 (21); also elsewhere on the board
VCC_12V0: C147.1 (+), J1.A1 (1), J1.A2 (2), J1.A3 (3), J1.A4 (4), J1.A5 (5), J1.A6 (6), J1.A7 (7), J1.A8 (8), J1.A9 (9), J1.A10 (10); also elsewhere on the board
VSS: C147.2 (-), J1.A11 (11), J1.A12 (12), J1.A13 (13), J1.A14 (14), J1.A15 (15), J1.A16 (16), J1.A17 (17), J1.A18 (18), J1.A19 (19), J1.A20 (20), J1.A29 (29), J1.A38 (38), J1.B1 (1), J1.B2 (2), J1.B3 (3), J1.B4 (4), J1.B5 (5), J1.B6 (6), J1.B7 (7), J1.B8 (8), J1.B9 (9), J1.B10 (10), J1.B15 (15), J1.B18 (18), J1.B20 (20), J1.B22 (22), J1.B24 (24), J1.B27 (27), J1.B28 (28), J1.B29 (29), J1.B30 (30), J1.B31 (31), J1.B32 (32), J1.B33 (33), J1.B34 (34), J1.B35 (35), J1.B36 (36), J1.B37 (37), J1.B38 (38), J1.B39 (39), J1.B40 (40), J1.C5 (5), J1.C8 (8), J1.C22 (22), J1.C27 (27), J1.C32 (32); also elsewhere on the board

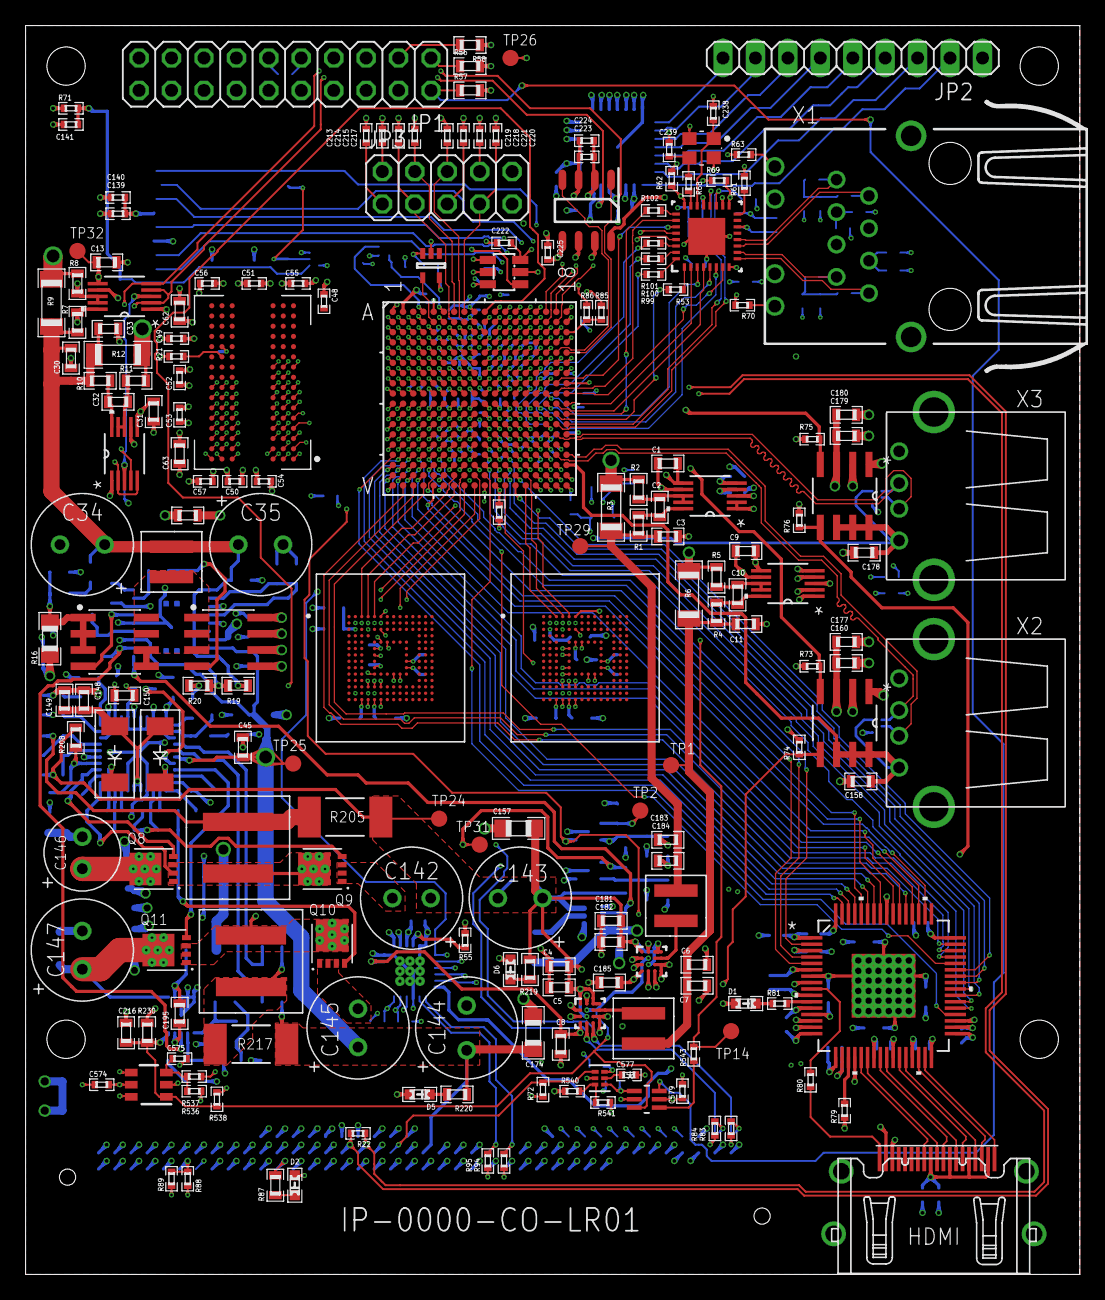
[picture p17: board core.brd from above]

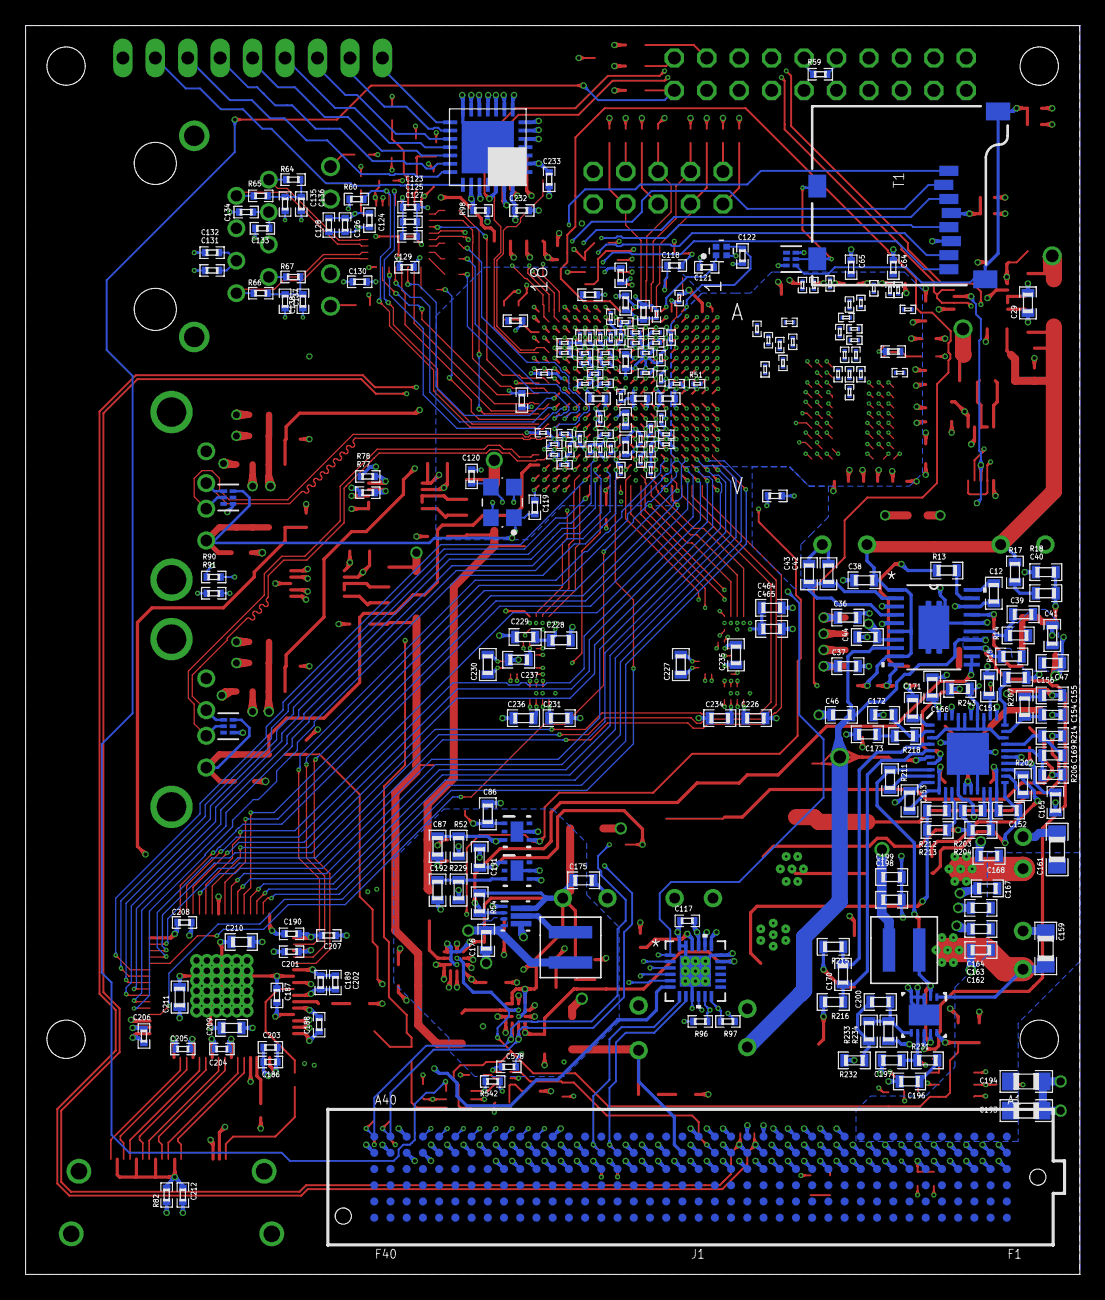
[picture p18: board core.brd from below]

Board: 10 copper layers, 82.5 x 97.8 mm, 446 parts (252 on the bottom side), 349 nets.
